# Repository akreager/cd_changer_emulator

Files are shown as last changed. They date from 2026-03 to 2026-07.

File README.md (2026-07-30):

# CD Changer Emulator

**Raspberry Pi-based CD changer emulator for vintage Kenwood car stereos**

Reverse-engineering the proprietary serial protocol used by 1990s Kenwood head units to communicate with their CD changers, and building an open-source emulator that replaces the changer with a Raspberry Pi — enabling unlimited music playback through the original stereo using its factory controls.
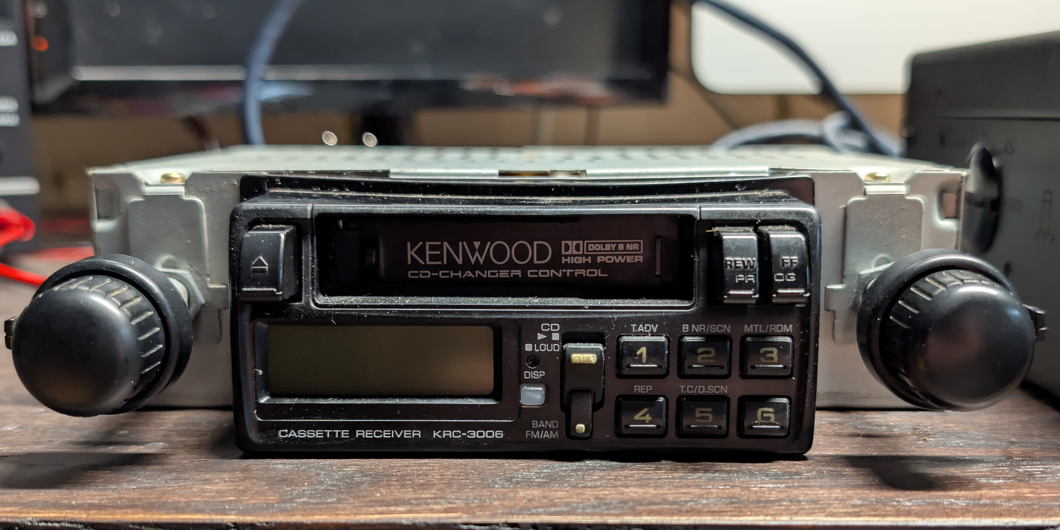
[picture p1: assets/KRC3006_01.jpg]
Close-up front view of KRC-3006 cassette receiver


## Project Status

🔬 **Phase: Protocol Reverse Engineering** — Capturing and decoding the synchronous serial protocol between a Kenwood KRC-3006 cassette receiver and a KDC-C717 10-disc CD changer.

### Current Milestone

**Phase 1 of TP-KRC3006-01 — power-on characterization — is complete.** Executed 2026-04-19 on the KRC-3006 with a KDC-C717 changer connected through the pass-through breakout board. Every recorded step passed; results are published in [TL-KRC3006-01-P1-20260419](./docs/records/TL-KRC3006-01-P1-20260419.pdf).

Findings that matter for the emulator design:

- **CH-CON (Pin 4) measures active-HIGH** — the line rises when the changer source is selected. This *conflicts* with the KDC-CX85 service manual, which documents it as active-LOW. To be re-confirmed against decoded traffic in Phase 2.
- **Pin 2 (GND) and Pin 6 (D.GND) show continuity** inside the head unit, which settles the grounding strategy for the HAT.
- **CLK (Pin 13) is gated, not continuous** — 0 Hz at idle, 31.6 Hz during playback, briefly ~100 Hz on a track change before settling back. These are DMM frequency readings on a gated line, not bit-rate measurements; bit-level clock timing awaits logic analyzer capture in Phase 2A.
- **Pin 10 (CH-DATAC) idles near 5 V**, not the LOW state predicted by the schematic analysis. Unexplained — still open.
- **The KDC-C717 is functional** — displays E-01 with no magazine, then loads and plays on insertion.

Testing runs inline through the DN-KRC3006-04 pass-through breakout board, serial number 1, assembled and verified per TP-KRC3006-02:
Close-up view of assembled pass-through breakout board

The KDC-CX85 originally used as the reference changer was diagnosed with a dead or degraded laser diode and retired. All further testing uses the KDC-C717:
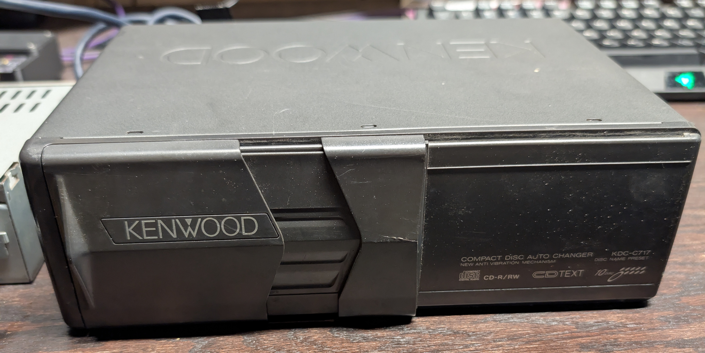
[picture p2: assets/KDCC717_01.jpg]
Close-up front view of KDC-C717 CD auto changer


For reference, the 13-pin mini DIN changer connector pinout:
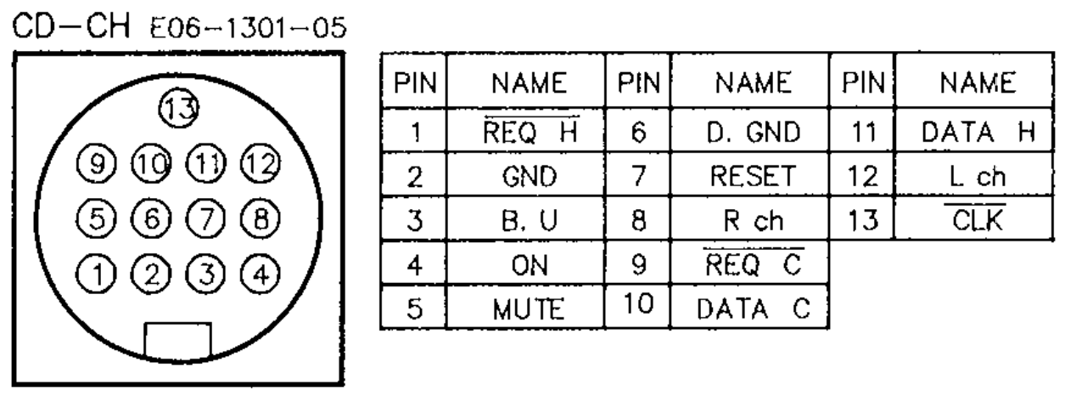
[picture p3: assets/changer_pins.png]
Kenwood 13-pin mini DIN CD changer connector pinout and signal names


### Immediate To-Do

- [ ] **Execute Phase 2A of TP-KRC3006-01** — Idle-state logic analyzer capture and first message decode: establish the bit clock, polling interval, and frame structure.
- [ ] **Execute Phase 2B** — Inline bidirectional capture of head unit ↔ KDC-C717 traffic. Inline capture is mandatory: the head unit will not switch to the changer source unless a changer is electrically present, so isolated head unit testing is impractical.
- [ ] **Execute Phase 3** — Command mapping: correlate each head unit control to its bus command and the changer's response, and compare against the Mictronics tables.
- [ ] **Resolve CLK directionality** — The CX85 service manual lists CLK as I/O. If Phase 2B confirms it is bidirectional, the fixed-direction SN74LVC8T245 will not work for CLK; an SN74LVC1T45 (independent DIR pin) is the planned substitute.
- [ ] **Continue the emulator HAT schematic** — The protocol and audio front end is placed (ATtiny1616, two SN74LVC8T245 level shifters, PCM5102A DAC, 40-pin Pi header, 13-pin mini DIN changer port, supporting passives). The automotive power supply section is not yet drawn and no PCB layout has begun; the schematic cannot be finalized until command mapping is complete.

### Completed

- [x] **Schematic analysis** — Detailed analysis of both KRC-3006 and KDC-CX85 service manuals. Confirmed 5V TTL bus signaling, inline series resistors of 100Ω–7.5KΩ on the head unit side against a uniform 100Ω on the changer side, all total series impedances between 200Ω and 7.6KΩ, COMMSW protocol selection, and always-live 12V on the B.U. pin. **Rev C corrected an earlier error:** R145/R146 (100K) are pull-downs to ground that define the idle-LOW state on DATA H and CLK — they are *not* inline series elements, and bus edges are consequently fast (τ ≈ 2 ns), not slow. No edge-rate compensation is needed. (DN-KRC3006-02 Rev C)
- [x] **Breakout board design** — KiCad layout with two 13-pin mini DIN connectors and 2.54mm pin headers (ground adjacent to each signal) using Kenwood signal names on silkscreen. (DN-KRC3006-04)
- [x] **Connector footprint verification** — 3D-printed mockup confirmed pin spacing before committing to fab.
- [x] **Breakout board ordered** — 3 boards, OSH Park standard fab.
- [X] **Completed TP-KRC3006-02** — Receive, inspect, assemble and verify pass-through breakout board serial number 1.
- [X] **Set up test bench** — Bench wiring, logic analyzer connections, and a custom staged power adapter with two toggle switches that simulate constant and ignition-switched power independently.
- [X] **Troubleshoot CX85** — Initial tests showed the CD changer laser diode is dirty or degraded (E-04, all discs unreadable). Unit deemed inoperable and retired. Further testing is carried out with a KDC-C717 CD changer. (DN-KRC3006-06)
- [X] **Completed Phase 1 of TP-KRC3006-01** — Power-on characterization with the KDC-C717 inline: supply and idle current draw, 13-pin DIN idle voltages on every signal pin, CH-CON polarity, CLK gating behavior, and pin 2 ↔ pin 6 ground continuity. Record: TL-KRC3006-01-P1-20260419.

## What This Project Does

This project emulates a Kenwood CD changer on the 13-pin round DIN connector used by mid-1990s Kenwood head units. The emulator responds to all head unit commands (play, stop, next/previous track, disc selection, repeat, shuffle) and streams audio from a Raspberry Pi through the stereo's built-in amplifier.

### Features (Planned)

- **Full protocol emulation** — Head unit displays disc number and track number.
- **10 virtual disc slots** — Map playlists to CD1–CD0, just like a real magazine. "Magazine overflow" (a playlist of playlists) allows more than ten playlists per magazine, wrapping to the next bank automatically when disc 10 finishes.
- **Web-based library management** — Build playlists and load virtual magazines from your phone over WiFi. FLAC-only library. By design there are **no playback controls in the web UI** — every transport command comes from the head unit, the same as a real changer. (DN-KRC3006-05)
- **Automotive power management** — Supercapacitor-backed graceful shutdown, cranking ride-through, battery monitoring.
- **WiFi standby mode** — When parked at home, the Pi stays on and connects to your home network for easy music transfers and system updates.
- **Custom Raspberry Pi HAT** — Single PCB with ATtiny1616 protocol controller, PCM5102A I2S DAC, automotive power supply, designed for JLCPCB or similar assembly.

## Target Hardware

| Component | Role |
|---|---|
| Kenwood KRC-3006 (or similar mid-90s Kenwood head unit) | The stereo — device under test |
| Kenwood KDC-C717 | CD auto changer — reference changer for protocol capture |
| Raspberry Pi 5 | Media server, web interface, audio playback |
| ATtiny1616 | Real-time Kenwood protocol handler (on custom HAT), run at 3.3V to match Pi GPIO natively |
| SN74LVC8T245PWR ×2 | 3.3V ↔ 5V bus level shifting, one per direction |
| PCM5102A I2S DAC | Digital-to-analog audio conversion |
| 1 TB NVMe SSD | Music storage (avoids SD card corruption) |
| SparkFun TOL-18627 USB Logic Analyzer | Protocol capture and analysis |
| Custom staged power adapter | Two toggle switches simulating constant and ignition power independently on the bench |

## Target Vehicle

Any vintage automobile still using a Kenwood head unit with CD changer control. I am building this and testing around a KRC-3006 head unit due to it being the only shaft style cassette deck with a CD changer control port. My vehicle for this project is a 1985 Chevrolet C10 Silverado. The power supply design accounts for the electrically noisy environment of older vehicles without modern filtering.

## Repository Structure

```
cd_changer_emulator/
├── assets/                  # Project assets. Photos and screenshots.
├── docs/                    # Project documentation
│   ├── TP-KRC3006-01.odt    # Test plan 1: Protocol capture test procedure (IEEE 829)
│   ├── TL-KRC3006-01.ods    # Test log 1: Companion log workbook to TP-KRC3006-01
│   ├── TP-KRC3006-02.odt    # Test plan 2: Breakout board test plan
│   ├── TL-KRC3006-02.odt    # Test log 2: Breakout board test log
│   ├── TP-KRC3006-03.odt    # Test plan 3: Emulator test procedure (IEEE 829)
│   ├── TL-KRC3006-03.ods    # Test log 3: Companion log workbook to TP-KRC3006-03
│   ├── DN-KRC3006-01.md     # Design note 1: HAT design research
│   ├── DN-KRC3006-02.md     # Design note 2: Schematic analysis
│   ├── DN-KRC3006-03.md     # Design note 3: Bluetooth stretch goal
│   ├── DN-KRC3006-04.md     # Design note 4: Breakout board design
│   ├── DN-KRC3006-05.md     # Design note 5: Web application design for library management
│   ├── DN-KRC3006-06.md     # Design note 6: Kenwood CD changer error codes
│   ├── protocol/            # Decoded protocol data
│   └── records/             # Completed, filled-out test logs (published as PDF)
├── firmware/                # ATtiny1616 firmware (Arduino/megaTinyCore)
│   └── src/
├── software/                # Raspberry Pi software
│   ├── flask-app/           # Web interface — legacy name; being superseded by FastAPI
│   ├── mpd-config/          # Legacy name; playback is moving to python-mpv
│   ├── power-mgmt/          # ATtiny UART bridge and power state management
│   └── wifi-manager/        # AP/client mode switching
├── hardware/                # KiCad PCB design files
│   ├── kicad/
│   │   ├── changer cable breakout/  # Pass-through breakout board (complete, fabbed)
│   │   ├── emulator hat/            # Raspberry Pi HAT (schematic in progress)
│   │   └── lib/                     # Shared custom symbols and footprints
│   ├── gerbers/             # Manufacturing files
│   └── bom/                 # Bill of materials with JLCPCB part numbers
├── captures/                # Logic analyzer captures (.sr files)
├── diagrams/                # WaveDrom timing, Mermaid state machines, draw.io blocks
└── reference/               # Datasheets, protocol documentation, forum archives
```

## Kenwood Compatibility

This project targets the **"O protocol"** (Old protocol) used by Kenwood head units with the round 13-pin DIN CD changer connector, roughly 1990–1998. Known compatible head units include models in the KRC series (cassette receivers) and some KDC series (CD receivers) from that era [citation needed].

Later Kenwood units with a rectangular changer connector use the "C protocol" (New protocol), which has different command encoding. This project does not currently target the C protocol, but the hardware and architecture could be adapted [citation needed].

## Documentation

The project follows a documentation-first approach using IEEE 829-inspired test procedures. All documentation lives in the `docs/` directory. Markdown is preferred wherever it fits, so design notes are written in Markdown and render directly on GitHub. The test plans and companion logs are currently kept in Open Document Format because they are table- and form-heavy, but no particular document format is required.

Test plans and test logs are created and maintained as matched pairs sharing a sequence number — `TP-KRC3006-01` defines what gets tested and how, and `TL-KRC3006-01` is where results are recorded. Filled-out copies of a log are published as PDF in `docs/records/` as each phase completes.

| Document Name | Type | Description |
|----|---|---|
| [TP-KRC3006-01](./docs/TP-KRC3006-01.odt) | Test Plan | Initial test plan for capturing messages between CD changer and head unit |
| [TL-KRC3006-01](./docs/TL-KRC3006-01.ods) | Test Log | Companion log workbook to TP-KRC3006-01 |
| [TP-KRC3006-02](./docs/TP-KRC3006-02.odt) | Test Plan | Breakout board test plan |
| [TL-KRC3006-02](./docs/TL-KRC3006-02.odt) | Test Log | Breakout board test log |
| [TP-KRC3006-03](./docs/TP-KRC3006-03.odt) | Test Plan | Test plan for creating and testing protocol emulation through full audio integration |
| [TL-KRC3006-03](./docs/TL-KRC3006-03.ods) | Test Log | Companion log workbook to TP-KRC3006-03 |
| [DN-KRC3006-01](./docs/DN-KRC3006-01.md) | Design Note | HAT design research — ATtiny1616 selection, PCM5102A DAC circuit, automotive power supply with supercap, WiFi architecture, JLCPCB assembly |
| [DN-KRC3006-02](./docs/DN-KRC3006-02.md) | Design Note | Schematic analysis — KRC-3006 head unit and KDC-CX85 changer signal routing, series resistor values, protocol variant identification |
| [DN-KRC3006-03](./docs/DN-KRC3006-03.md) | Design Note | Bluetooth stretch goal — wireless audio streaming while retaining factory head unit controls |
| [DN-KRC3006-04](./docs/DN-KRC3006-04.md) | Design Note | Breakout board design — pass-through 13-pin mini DIN breakout with logic analyzer headers |
| [DN-KRC3006-05](./docs/DN-KRC3006-05.md) | Design Note | Web Application Design for Emulator Library Management |
| [DN-KRC3006-06](./docs/DN-KRC3006-06.md) | Design Note | Kenwood CD Changer Error Codes |

Per-document revision status is tracked in the [documentation index](./docs/README.md).

### Completed Test Records

| Record | Covers | Date |
|----|---|---|
| [TL-KRC3006-01-P1-20260419](./docs/records/TL-KRC3006-01-P1-20260419.pdf) | TP-KRC3006-01 Phase 1 — power-on characterization | 2026-04-19 |
| [TL-KRC3006-02-01-20260410](./docs/records/TL-KRC3006-02-01-20260410.pdf) | TP-KRC3006-02 — breakout board serial number 1 | 2026-04-10 |

## Building / Contributing

This project is in early development. If you have a compatible Kenwood head unit and want to help with protocol capture, testing, or firmware development, contributions are welcome.

### Prerequisites

- [Arduino IDE](https://www.arduino.cc/en/software) with [megaTinyCore](https://github.com/SpenceKonde/megaTinyCore) installed
- [PulseView](https://sigrok.org/wiki/PulseView) for logic analyzer captures
- [KiCad](https://www.kicad.org/) for PCB design
- Python 3 with [FastAPI](https://fastapi.tiangolo.com/) for the web interface and [python-mpv](https://github.com/jaseg/python-mpv) for playback
- [LibreOffice](https://www.libreoffice.org/) to open the test plans and logs (`.odt` / `.ods`)
- A UPDI programmer for the ATtiny1616 ([Adafruit UPDI Friend](https://www.adafruit.com/product/5879) or DIY with a serial adapter and resistor)

## References

- [Mictronics CDC Protocol Documentation](https://www.mictronics.de/) (Kenwood command tables)
- [Elektroda.pl Kenwood Slim CD Changer Emulator](https://www.elektroda.pl/rtvforum/topic536235.html) (szymtro's 8051 implementation)
- [AVRFreaks: Kenwood CD Changer → Serial Strings](https://www.avrfreaks.net/forum/kenwood-cd-changer-serial-strings)
- [Pinouts.ru: Kenwood 13-pin DIN connector](https://old.pinouts.ru/CarAudio/kenwood_cd_changer_pinout.shtml)
- [SpenceKonde/megaTinyCore](https://github.com/SpenceKonde/megaTinyCore) (ATtiny1616 Arduino support)
- [pyupdi / pymcuprog](https://github.com/mraardvark/pyupdi) (UPDI programming from Raspberry Pi)

## License

This project is licensed under the [MIT License](LICENSE) — you're free to use, modify, and distribute this project for any purpose, including commercial use.

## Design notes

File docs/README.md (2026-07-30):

# KRC-3006 CD Changer Emulator — Documentation Index

This folder contains all project documentation for the KRC-3006 reverse engineering and CD changer emulator project.

---

## File Format

There is no mandated document format. **Markdown (`.md`) is preferred wherever it fits** — such as the design notes and this README — so documents render directly on GitHub. Table- and form-heavy documents like the test plans and logs are currently kept in Open Document Format (`.odt` / `.ods`) and open in LibreOffice or any compatible editor, but any format may be used where it serves the document best.

Formats currently in use:
- Markdown (`.md`) — design notes and READMEs
- Open Document Format (`.odt` / `.ods`) — test plans and logs
- Timing diagrams (WaveDrom `.json`)
- State machine diagrams (Mermaid `.mmd`)

---

## Naming Convention

Documents follow this structure:

```
TT-KRC3006-NN
```

| Field | Description |
|---|---|
| `TT` | Two-letter document type code (see below) |
| `KRC3006` | Project identifier — fixed for all documents in this project |
| `NN` | Two-digit sequence number, zero-padded (01, 02, 03 …) |

### Document Type Codes

| Code | Type | Description |
|---|---|---|
| `TP` | Test Plan | Defines test objectives, scope, phases, pass/fail criteria, and procedure for a body of testing work. |
| `TL` | Test Log | Companion data-collection workbook to a Test Plan. Captures actual results, observations, and outcomes as testing is executed. Always paired 1:1 with a TP of the same number. |
| `DN` | Design Note | Records design decisions, research findings, architectural intent, or reference material. Not a procedure document — captures the *why* and *what*, not the *how*. |

---

## Document Register

| Document | Title | Paired With | Status |
|---|---|---|---|
| TP-KRC3006-01 | Protocol Reverse Engineering Test Plan | TL-KRC3006-01 | **Rev B** — in progress; Phase 1 complete |
| TL-KRC3006-01 | Test Log — Companion to TP-01 | TP-KRC3006-01 | **Rev B** — Phase 1 recorded 2026-04-19 |
| TP-KRC3006-02 | Breakout Board Bare Board Testing, Assembly, and Verification | TL-KRC3006-02 | Board Serial Number 1 Completed |
| TL-KRC3006-02 | Breakout Board Test Log | TP-KRC3006-02 | Board Serial Number 1 Completed |
| TP-KRC3006-03 | Protocol Emulation Test Plan | TL-KRC3006-03 | Waiting for TP-01 Completion |
| TL-KRC3006-03 | Test Log — Companion to TP-03 | TP-KRC3006-03 | Template prepared; waiting for TP-01 Completion |
| DN-KRC3006-01 | Hardware Design Research | — | In progress |
| DN-KRC3006-02 | Schematic Analysis | — | **Rev C** — bus impedance corrected |
| DN-KRC3006-03 | Bluetooth Integration & Button Remapping | — | Concept |
| DN-KRC3006-04 | 13-Pin Mini DIN Protocol Sniffer Breakout Board | — | Complete |
| DN-KRC3006-05 | Web Application Design for Emulator Library Management | — | Draft |
| DN-KRC3006-06 | Kenwood CD Changer Error Codes | — | Complete |

TP-KRC3006-01 Rev B (2026-04-12) restricted the plan's scope to protocol reverse engineering only — emulator development and audio integration moved to TP-KRC3006-03 — replaced KDC-CX85 references with the KDC-C717, and added Phase 2B for changer-connected capture through the breakout board.

### TP-KRC3006-01 Phase Progress

| Phase | Scope | Status |
|---|---|---|
| 1 | Power-on characterization — supply, idle bus voltages, CH-CON polarity, ground continuity | Complete (2026-04-19) |
| 2A | Idle-state capture and first message decode | Not started |
| 2B | Inline bidirectional capture, head unit ↔ KDC-C717 | Not started |
| 3 | Command mapping | Not started |

---

## TP / TL Pairing

Test Plans and Test Logs are always created and maintained as a matched pair. A TP defines what will be tested and how; the companion TL is where results are recorded as work is executed. They share the same sequence number — `TP-KRC3006-01` and `TL-KRC3006-01` are two halves of the same body of test work.

When a new test plan is created, a corresponding log document must be created at the same time. A filled out *copy* of a test log is to be placed in the `records/` sub directory.

The working log in this folder stays live and accumulates results as phases are executed. Each time a phase or unit is finished, a snapshot of the filled-out log is published to `records/` and named `{TL-ID}-{phase or unit}-{YYYYMMDD}`.

### Published Records

| Record | Covers | Date |
|---|---|---|
| TL-KRC3006-01-P1-20260419 | TP-01 Phase 1 — power-on characterization | 2026-04-19 |
| TL-KRC3006-02-01-20260410 | TP-02 — breakout board serial number 1 | 2026-04-10 |

---

*This README is a living document and should be updated whenever a new document is added to the register.*

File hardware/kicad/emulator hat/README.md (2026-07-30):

# Kenwood CD Changer Emulator HAT

KiCad project for a Raspberry Pi 5 HAT that emulates a Kenwood CD changer over the proprietary "O protocol" bus. Designed for the KRC-3006 shaft-style cassette head unit, replacing a 10-disc changer with unlimited FLAC playback controlled entirely from the factory head unit.

## Current Status

**Early schematic layout.** The protocol and audio front end is placed — ATtiny1616, two SN74LVC8T245 level shifters, PCM5102A DAC, 40-pin Pi header, and the 13-pin mini DIN changer port — along with supporting passives based on the PCM5102A reference design. The automotive power supply section has not been drawn yet, and no PCB layout work has begun.

Protocol reverse engineering via the breakout board (DN-KRC3006-04) is the active priority. Full command mapping must be complete before the HAT schematic can be finalized.

## Design Overview

The HAT consolidates four subsystems onto a single board:

- **ATtiny1616 protocol controller** — Handles all real-time Kenwood bus communication at 3.3V, translated to 5V bus levels via two SN74LVC8T245PWR level shifters. Communicates with the Pi over a dedicated UART.
- **PCM5102A I2S DAC** — Converts digital audio from the Pi to analog line-level output for the head unit's CD changer input.
- **Automotive power supply** — Accepts 12V from the head unit (constant B.U. and ignition-switched), regulates to 5V/3.3V with power sequencing and soft-shutdown support.
- **Connectors and interface** — 13-pin mini DIN bus connection, UPDI programming header (dedicated UART3 on GPIO4/5), status LEDs, test points.

Every bus signal will carry a 100 Ω inline series resistor, matching the protection scheme the KDC-CX85 uses on its own connector. Per DN-KRC3006-02 Rev C the bus is a conventional fast 5V TTL/CMOS bus — the head unit's own series resistors range from 100 Ω to 7.5 KΩ and the 100K parts on DATA H and CLK are pull-downs to ground that define the idle-LOW state, not series elements. No edge-rate compensation or Schmitt-trigger conditioning is needed.

All music logic — playlist management, FLAC decoding, library browsing — runs on the Raspberry Pi via python-mpv. The ATtiny handles only the protocol state machine and handshake timing.

## Settled by Phase 1 Testing

TP-KRC3006-01 Phase 1 (power-on characterization, 2026-04-19) resolved two questions that affect this board:

- **Audio ground topology** — Pins 2 (GND) and 6 (D.GND) measured continuous inside the head unit. They can be treated as a single ground on the HAT.
- **CH-CON (Pin 4) polarity** — Measured active-HIGH: the line rises when the changer source is selected. This conflicts with the KDC-CX85 service manual, which documents it as active-LOW, so it will be re-confirmed against decoded traffic in Phase 2 before the input stage is committed.

Phase 1 also found Pin 10 (CH-DATAC) idling near 5 V rather than the LOW state the schematic analysis predicted. That is still unexplained and may affect how the HAT drives or reads that line.

## Open Constraints

Several items still depend on data from the ongoing reverse engineering effort (TP-KRC3006-01):

- **CLK signal directionality** — The CX85 service manual lists CLK as I/O on the changer side. If Phase 2B confirms it is bidirectional, the CLK channel must use an SN74LVC1T45 (independent DIR pin) instead of the fixed-direction 74LVC8T245.
- **Power sequencing** — The ATtiny must be ready to respond before the Pi finishes booting (~20s). Autonomous status responses during early boot may be required.
- **DAC output level matching** — Analog output must match the stock changer's level to avoid volume discontinuity. To be verified during integration testing.

## Related Documentation

| Document | Description |
|---|---|
| DN-KRC3006-01 | HAT design research — component selection, pin mapping, architecture |
| DN-KRC3006-02 Rev C | KRC-3006 and KDC-CX85 schematic analysis — bus impedance, signal conditioning |
| DN-KRC3006-04 | 13-pin mini DIN breakout board (complete, used for protocol capture) |
| TP-KRC3006-01 Rev B | Reverse engineering test plan (active — Phase 1 complete, Phase 2A next) |
| TP-KRC3006-03 | Emulator development and integration test plan (waiting for TP-01) |

## License

MIT — see repository root.

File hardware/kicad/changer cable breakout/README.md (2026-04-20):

# KRC-3006 Pass-Through Breakout Board (DN-KRC3006-04)

## Purpose

This KiCad project implements a passive, pass-through breakout board for the Kenwood KRC-3006 head unit's 13-pin mini DIN connector. The board provides:

- **Signal routing** between the KRC-3006 and connected CD autochanger.
- **Accessible test points** for bus signal analysis and protocol reverse engineering.
- **Isolated audio path** with independent head unit and changer TRS audio jack connectors.

## Current Status

**COMPLETE AND TESTED** — Boards received 2026-03-28 from OSH Park. Assembly and verification of S/N 1 completed 4/5. Breakout board is fully functional and ready for protocol reverse engineering work.  
Picture of assembled break-out board

## Schematic Summary

| Ref Des | Component | Function |
|---|---|---|
| J1 | SDD-130J, 13-pin mini DIN female | Head unit side connector (front side) |
| J2 | SDD-130J, 13-pin mini DIN female | Changer side connector (back side) |
| J3 | 1×11 female pin header, 2.54 mm pitch | Digital/control signal test points |
| J4 | STX-3100-3NB, 3.5 mm TRS audio jack | Head unit side audio breakout |
| J5 | STX-3100-3NB, 3.5 mm TRS audio jack | Changer side audio breakout |

## J1/J2 Pinout
13Pin Mini Din Pinout
| Pin | Signal | Description |
|-----|---|---|
| 1 | REQ H (Active Low)  | Request handshake output from head unit. |
| 2 | GND | Audio ground. |
| 3 | B.U.  | Battery Unswitched. |
| 4 | ON  | Changer connect/enable signal. |
| 5 | MUTE  | Mute request line. |
| 6 | D. GND | Digital ground. |
| 7 | RESET  | Reset pulse output to changer. |
| 8 | R CH  | Right audio channel, analog. |
| 9 | REQ C (Active Low)  | Request handshake output from changer to head unit. |
| 10 | DATA C  | Serial data from changer to head unit. |
| 11 | DATA H  | Serial data from head unit to changer. |
| 12 | L CH  | Left audio channel, analog. |
| 13 | CLK (Active Low)  | Synchronous clock. |

## J3 Pinout

|  J3 Pin  |  J1 Pin  |  Signal  |
| --- | --- | --- |
| 1 | 2 |  GND  |
| 2 | 4 |  ON (CH-CON)  |
| 3 | 3 |  B.U. (+14V)  |
| 4 | 7 |  RESET  |
| 5 | 6 |  D. GND  |
| 6 | 1 |  REQ H (Active Low)  |
| 7 | 9 |  REQ C (Active Low)  |
| 8 | 5 |  MUTE  |
| 9 | 10 |  DATA C  |
| 10 | 11 |  DATA H  |
| 11 | 13 |  CLK (Active Low)  |

## J4 Pinout

| J4 Pin | J1 Pin | Signal |
| --- | --- | --- |
| 1 | 2 | GND |
| 2 | 8 | L CH to head unit |
| 3 | 12 | R CH to Head unit |

## J5 Pinout

| J5 Pin | J2 Pin | Signal |
| --- | --- | --- |
| 1 | 2 | GND |
| 2 | 8 | L CH from changer |
| 3 | 12 | R CH from changer |

## Audio Interception

The audio channels (Pin 8 - R CH and Pin 12  L CH) are not routed as a direct pass-through between J1 and J2. Instead, they are broken out to two 3.5 mm TRS audio jacks mounted on the right edge of the board:

- **J4** — Head unit side audio. Tip = R CH, Ring = L CH, Sleeve = GND.
- **J5** — Changer side audio. Tip = R CH, Ring = L CH, Sleeve = GND.

The audio jacks use a standard 3-conductor (TRS) footprint with no switching contacts. When nothing is plugged in, the audio pins on both the head unit and changer sides float.

This topology enables three operating modes:

| Mode | Configuration | Use Case |
|---|---|---|
| **Audio pass-through** | Connect J4 to J5 with a male-to-male 3.5 mm TRS cable. | Normal protocol capture with authentic changer audio reaching the head unit. |
| **Audio intercept** | Connect monitoring equipment (oscilloscope, audio recorder, powered speakers) to J5. | Listen to or record the changer's audio output without routing it to the head unit. |
| **Audio injection** | Connect an external audio source to J4. Leave J5 disconnected or connected to monitoring equipment. | Feed test tones or music from a phone, DAC, or Raspberry Pi directly into the head unit's audio input path. Useful for verifying the audio path independently of changer protocol state. |

Audio pass-through requires the external cable. The board cannot function as a fully transparent sniffer without it. This is an intentional design decision — the separate jacks provide flexibility that a hardwired pass-through cannot.

## Next Steps

This board is now ready to support:
1. **TP-KRC3006-01 Phase 1** — Passive capture of KRC-3006 ↔ KDC-C717 traffic
2. **TP-KRC3006-01 Phase 2a/2b** — Analysis with head unit alone, then with real changer through breakout
3. **TP-KRC3006-03** — Emulator development and integration testing

## References

- Service manual: Kenwood KRC-3006 Cassette Head Unit
- Service manual: Kenwood KDC-C717 CD Changer
- Related design docs: DN-KRC3006-02 (Schematic Analysis), DN-KRC3006-04

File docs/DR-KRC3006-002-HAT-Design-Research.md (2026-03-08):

# KRC-3006 CD Changer Emulator — Raspberry Pi HAT Design Research

## Document ID: DR-KRC3006-002
**Date:** ___  
**Author:** ___  
**Status:** Pre-design research — to inform schematic and layout

---

## 1. System Architecture Overview

The final product is a single Raspberry Pi HAT PCB that plugs onto the Pi 3B+ GPIO header and provides everything needed to emulate a Kenwood CD changer. The HAT consolidates four subsystems:

1. **ATtiny1616 Protocol Controller** — Handles all real-time Kenwood bus communication
2. **PCM5102A I2S DAC** — Converts digital audio from the Pi to analog line-level output
3. **Automotive Power Supply** — Steps 12V from the Kenwood head unit down to 5V and 3.3V
4. **Connectors & Interface** — 13-pin DIN breakout, UPDI programming header, status LEDs

The Raspberry Pi 3B+ provides: WiFi AP for the web control interface, media storage (USB or SD), audio playback via MPD/Flask, and UART communication with the ATtiny.

---

## 2. ATtiny1616 Selection Rationale

### Why ATtiny1616 (not ATtiny85 or ATtiny3216)

| Parameter | ATtiny85 | ATtiny1616 | ATtiny3216 |
|---|---|---|---|
| Pins (GPIO) | 6 | 18 | 18 |
| Flash | 8KB | 16KB | 32KB |
| SRAM | 512B | 2KB | 2KB |
| Hardware UART | No (USI only) | Yes (1x) | Yes (1x) |
| Hardware SPI | No (USI only) | Yes (1x) | Yes (1x) |
| Ext. Interrupts | Limited | All pins | All pins |
| CCL (Custom Logic) | No | Yes (2 LUT) | Yes (2 LUT) |
| Max Clock | 20MHz | 20MHz | 20MHz |
| JLCPCB Part # | Various | **C507118** | C507136 |
| JLCPCB Price | ~$0.30 | **~$0.49** | ~$0.80 |
| Package | SOIC-8 | **QFN-20 (3x3mm)** | QFN-20 (3x3mm) |

**Decision: ATtiny1616** — The ATtiny85 simply doesn't have enough I/O (need 7 bus pins + UART TX/RX = 9 minimum). The 1616 provides exactly what's needed with headroom. The 3216 doubles the flash but is otherwise identical and costs more — 16KB is plenty for the protocol state machine.

### JLCPCB Assembly Notes
- JLCPCB Part: **C507118** (ATTINY1616-MNR, QFN-20-EP 3x3mm)
- Assembly type: SMT, compatible with both Economic and Standard PCBA
- MSL Level 1 (no baking required)
- The QFN-20 package requires proper thermal pad design — include thermal vias under the exposed pad

### Pin Assignment Plan

The ATtiny1616 in the QFN-20 package has pins PA0-PA7 and PB0-PB5, plus the UPDI pin (PA0 is shared with UPDI by default but can be freed via fuse setting).

**Recommended pin mapping:**

| ATtiny Pin | Function | Kenwood Signal | Direction | Notes |
|---|---|---|---|---|
| PA1 | UART TX | → Pi GPIO15 (RXD) | Output | Hardware USART0 TXD |
| PA2 | UART RX | ← Pi GPIO14 (TXD) | Input | Hardware USART0 RXD |
| PA3 | SPI SCK | CLK (Pin 13) | Input | Use as ext interrupt for clock |
| PA4 | SPI MOSI | CH-DATAH (Pin 11) | Input | Data from head unit |
| PA5 | SPI MISO | CH-DATAC (Pin 10) | Output | Data to head unit |
| PA6 | GPIO | CH-REQH (Pin 1) | Input | Ext interrupt on falling edge |
| PA7 | GPIO | CH-REQC (Pin 9) | Output | Changer handshake |
| PB0 | GPIO | CH-CON (Pin 4) | Input | Changer connect detect |
| PB1 | GPIO | CH-MUTE (Pin 5) | Output | Mute request |
| PB2 | GPIO | CH-RST (Pin 7) | Input | Reset detect |
| PB3 | GPIO | Status LED 1 | Output | Activity indicator |
| PB4 | GPIO | Status LED 2 | Output | Error indicator |
| PB5 | GPIO | (spare) | — | Reserve for future use |
| PA0 | UPDI | Programming | Bidir | In-circuit programming from Pi |

### Level Shifting: NOT Required
Both the ATtiny1616 (running at 5V) and the Kenwood bus (5V TTL) are at the same voltage level. However, the Pi's GPIO is 3.3V. For the UART connection:
- **ATtiny TX → Pi RX**: Needs a voltage divider (2.2kΩ / 3.3kΩ) to drop 5V to ~3.3V
- **Pi TX → ATtiny RX**: The ATtiny's 5V logic reads 3.3V as HIGH (Vih min = 0.6×Vcc = 3.0V at 5V supply, so 3.3V is marginal). Run the ATtiny at 3.3V instead if this is a concern, OR add a level shifter IC. Running at 3.3V simplifies things significantly but must be verified against Kenwood bus voltage requirements.

**Alternative: Run ATtiny1616 at 3.3V** — The 1616 operates from 1.8V to 5.5V and runs at full 20MHz speed at 3.3V. The Kenwood bus is 5V but the ATtiny's 3.3V output high would read as 3.3V on the bus. Whether the Kenwood head unit reads 3.3V as a valid HIGH needs verification during Phase 3 testing. If it doesn't work, add a 74LVC245 or TXB0108 level shifter.

### UPDI In-Circuit Programming from the Pi
The ATtiny 1-series uses UPDI (Unified Program and Debug Interface) — a single-wire protocol that can be driven by a standard UART with a resistor and diode. The pyupdi/pymcuprog tools run on the Pi.

**Circuit for Pi-based UPDI programming:**
```
Pi GPIO14 (TX) ---[470Ω]---+--- ATtiny UPDI pin
                            |
Pi GPIO15 (RX) ---[Schottky]---+
                  (cathode to TX side)
```
A GPIO-controlled MOSFET can disconnect this circuit during normal operation so the UART is free for the ATtiny ↔ Pi command link. Alternatively, use a second UART (the Pi 3B+ has a mini-UART on GPIO14/15 and the PL011 UART available when Bluetooth is moved).

---

## 3. PCM5102A I2S DAC Circuit

### I2S Connection to Pi GPIO Header

| Pi GPIO | Pi Header Pin | PCM5102A Pin | Signal |
|---|---|---|---|
| GPIO18 | Pin 12 | BCK | Bit clock |
| GPIO19 | Pin 35 | LRCK | L/R word clock |
| GPIO21 | Pin 40 | DIN | Serial data |
| — | — | SCK | **Tie to GND** (self-generated) |

### PCM5102A Configuration Pins (active-LOW, active during power-up)

| Pin | Setting | Effect |
|-----|---|---|
| FMT (H4L) | **LOW** (GND) | I2S format (required for Pi) |
| FLT (H1L) | LOW (GND) | Normal latency filter |
| DMP (H2L) | LOW (GND) | Normal de-emphasis |
| XSMT | **HIGH** (3.3V via 47kΩ pull-up) | Soft-mute OFF (unmuted) |

### Key Design Points
- **Power**: 3.3V only (from the on-board LDO, NOT from the Pi's 3.3V rail — keep DAC power isolated)
- **Decoupling**: Place 10µF + 100nF ceramic caps close to AVDD, DVDD, and CPVDD pins per TI datasheet Figure 38
- **Charge pump caps**: 2x 2.2µF between CAPP/CAPN pins (generates internal negative rail for bipolar output swing)
- **Output coupling caps**: 2x 2.2µF in series with each audio output (OUTL, OUTR) → to Kenwood pins 12 and 8
- **Output filter**: Optional low-pass RC filter after coupling caps (1kΩ + 100pF = ~1.6MHz cutoff) to suppress any ultrasonic content
- **Ground**: Separate analog ground pour under the DAC, connected to digital ground at a single star point

### Linux Configuration
Add to `/boot/config.txt`:
```
dtoverlay=hifiberry-dac
```
Verify with: `aplay -l` → should show `snd_rpi_hifiberry_dac`

### JLCPCB Parts
- PCM5102A: Search JLCPCB parts library — TI's PCM5102APWR (TSSOP-20) is the target. **Check stock before layout** — this part has had availability issues. The PCM5102 (non-A) is an acceptable alternative (same pinout, slightly different specs).
- If PCM5102A is unavailable at JLCPCB, consider: (a) using a pre-built GY-PCM5102 module soldered to the HAT via header pins, or (b) switching to PCM5122 which adds I2C volume control but requires a more complex driver setup.

---

## 4. Automotive Power Supply & Energy Storage

### 4.1 Target Vehicle: 1985 Chevrolet C10/K10 Silverado

The target installation vehicle significantly impacts power supply design. An '85 Silverado presents a harsher electrical environment than modern vehicles:

- **Ignition system**: GM HEI (High Energy Ignition) distributor — every spark event collapses an ignition coil inside the distributor cap, generating broadband EMI pulses that couple into the wiring harness. No modern ECU filtering or shielded ignition wires.
- **Charging system**: Internal-regulator alternator with no smart voltage management. Output is a relatively coarse 13.8–14.8V with significant AC ripple. Aging diodes in a 40-year-old alternator (even a replacement) can pass AC into the DC bus.
- **Cranking behavior**: The starter motor draws 150–250A. Battery voltage sags to 8V or lower during cranking, especially on cold Ohio mornings. The sag lasts 1–5 seconds depending on engine temperature and battery condition.
- **Load dump transients**: When large inductive loads disconnect (A/C compressor clutch, blower motor), voltage spikes of 40V+ can occur for microseconds to milliseconds.
- **Wiring age**: 40-year-old wiring with potentially corroded grounds and increased resistance throughout. Voltage drops across connectors may be significant.
- **No modern filtering**: No CAN bus, no body control module, no suppression capacitors on relays. What the alternator and ignition system produce, the wiring carries.

**Does the Kenwood head unit protect us?**
The KRC-3006 has its own internal voltage regulation for its logic and display, so the head unit itself survives automotive environments. However, Pin 3 (+12V) on the changer connector is almost certainly just battery voltage routed through a fuse and possibly a small series inductor — it was designed to power a CD changer's motors and laser optics, not sensitive digital electronics. The head unit protects *itself* but does NOT provide a clean, regulated, filtered supply on the changer port. **Verify this by examining the service manual schematic for the Pin 3 supply path.** The HAT must include its own full input protection and filtering.

### 4.2 Requirements

| Rail | Voltage | Max Current | Consumer |
|---|---|---|---|
| 5V | 5.0V ±5% | 2.5A | Raspberry Pi 3B+ (via GPIO header pins 2,4) |
| 3.3V | 3.3V ±3% | 200mA | ATtiny1616, PCM5102A, EEPROM, LEDs |

Input: 12V nominal from Kenwood Pin 3 (actual range in an '85 Silverado: 8V during cranking, 14.5V running, 40V+ transient spikes)

### 4.3 Input Protection Circuit (Strengthened for Vintage Vehicle)

```
Pin 3 (+12V) → [PTC fuse] → [Schottky] → [TVS] → [Pi-filter: C-L-C] → VBATT_FILT
```

**Full chain, in order from connector to buck converter input:**

1. **PTC resettable fuse** (1812 package, 2A hold / 4A trip): First line of defense against dead shorts during prototyping or wiring errors. Self-resetting means you don't blow a one-time fuse during development.

2. **Reverse polarity protection**: SS34 Schottky diode (40V, 3A) in series — low forward drop (~0.5V). Protects against accidentally swapping wires on the DIN connector. On an '85 Silverado with no polarity-protected connectors elsewhere in the vehicle, this is essential.

3. **Transient voltage suppression**: SMAJ24A TVS diode (24V standoff, 400W peak pulse power) from VBATT to GND. Clamps load dump spikes to ~39V (clamping voltage at 1A). This is the primary defense against the 40V+ transients that occur when inductive loads disconnect.

4. **Pi-filter for EMI** (upgraded from single LC for the HEI ignition environment):
   ```
   VBATT_PROT → [100µF electrolytic] → [22µH inductor, ≥3A sat] → [100µF electrolytic + 100nF ceramic] → VBATT_FILT
   ```
   The pi-filter (capacitor-inductor-capacitor) provides significantly better high-frequency rejection than a single LC stage. The first cap absorbs sharp transient edges from HEI ignition pulses. The inductor blocks conducted EMI. The second cap provides a clean, low-impedance supply to the buck converter input. The 100nF ceramic in parallel with the output electrolytic handles high-frequency noise that electrolytics are too slow to absorb.

   **Why a pi-filter matters for this vehicle**: HEI ignition pulses contain energy from DC up through 100+ MHz. A single LC filter has a resonant peak that can actually amplify noise at its resonant frequency. The pi-filter's double capacitive termination damps this resonance and provides a steeper rolloff.

5. **Optional: Common-mode choke** on the 12V and GND lines entering the HAT, before the pi-filter. This suppresses differential AND common-mode noise from the vehicle wiring harness. A Würth 744272102 or similar SMD common-mode choke rated for DC current would go here. This is the "belt and suspenders" approach for audio quality — if you hear alternator whine through the speakers during testing, add this.

### 4.4 12V → 5V Buck Converter

**Recommended: TPS5430DDAR** (TI)
- **5.5V–36V input range** — critical: survives automotive transients that the TVS clamps to ~39V
- 3A output continuous
- 500kHz switching frequency
- Widely available on JLCPCB/LCSC (check current stock)
- Well-documented application circuit in datasheet
- Internal UVLO (under-voltage lockout) at 5.5V — converter shuts down cleanly if input sags below this during cranking, rather than producing garbage output

**Alternative: MP1584EN** (MPS)
- Very popular on JLCPCB, often "basic" part = lower assembly fee
- **4.5V–28V input** — NOTE: lower max input than TPS5430. The TVS clamp voltage (~39V) exceeds this rating. If using MP1584, you MUST ensure the TVS clamps below 28V, or add a series resistor to drop voltage before the converter. **The TPS5430 is preferred for this vehicle.**
- 3A output, smaller package (SOIC-8)

**Layout critical**: Keep the input cap → SW pin → inductor → output cap loop as tight as possible. Place input caps directly adjacent to VIN and GND pins. Unbroken ground pour under the converter with vias to inner/back ground plane. Place the buck converter as far from the PCM5102A DAC as board space allows — opposite corners of the HAT is ideal.

### 4.5 5V → 3.3V LDO

**Recommended: AMS1117-3.3** (LCSC basic part, SOT-223)
- 1A output (far more than needed)
- Low cost, universally available at JLCPCB
- ~1.1V dropout means it works from 4.5V+ input
- Place 10µF tantalum + 100nF ceramic on input and output
- Position this LDO near the DAC, not near the buck converter — it acts as a secondary filter stage for the DAC's 3.3V supply

### 4.6 Supercapacitor Energy Storage

The supercap serves **three critical functions**:

1. **Graceful shutdown**: When ignition is turned off, the supercap provides enough energy for the Pi to execute `shutdown -h now` and complete filesystem sync, preventing SD card corruption.
2. **Cranking ride-through**: During engine cranking, battery voltage sags to 8V or below. The buck converter's UVLO may trip at 5.5V input, causing a momentary 5V dropout. The supercap holds the Pi's 5V rail steady through the 1–5 second cranking event.
3. **Brownout/glitch immunity**: Brief voltage dips from load switching (headlights, blower motor, power windows) are absorbed by the supercap without disturbing the Pi.

#### Energy Budget

**Graceful shutdown scenario:**
- Pi 3B+ during shutdown (headless, no USB devices): ~400–500mA at 5V
- Shutdown duration (lean Raspberry Pi OS Lite, non-essential services disabled): 5–8 seconds
- Energy needed: 0.5A × 5V × 8s = **20 joules**, plus margin

**Cranking ride-through scenario:**
- Pi running normally: ~500mA at 5V
- Cranking duration (worst case, cold start): 5 seconds
- Energy needed: 0.5A × 5V × 5s = **12.5 joules**

The shutdown scenario dominates. Target: **30 joules minimum** (50% safety margin).

#### Supercap vs. LiPo: Why Supercap Wins for This Application

| Factor | Supercap | LiPo |
|---|---|---|
| Temperature range | -40°C to +65°C | 0°C to +45°C (charge) |
| Ohio winter (-20°F) | Works fine | Cannot charge, may be damaged |
| Ohio summer (car interior 60°C+) | Works fine | Degrades rapidly, swelling risk |
| Cycle life | 500,000+ cycles | 300–500 cycles |
| Fire risk in hot car | None | Non-trivial |
| Self-discharge | Higher (days) | Lower (weeks) |
| Charge management | Simple (resistor) | Complex IC required |
| Aging/replacement | 10+ year life | 2–3 year replacement cycle |

**Verdict**: The supercap's temperature tolerance alone is decisive for an automotive application in Ohio. A LiPo would need active thermal management or seasonal removal, which is absurd for a car stereo accessory. The supercap's higher self-discharge is irrelevant because it recharges in seconds whenever the engine is running.

#### Recommended Implementation: Direct 5V Rail Supercap

The simplest effective approach is a supercap directly on the 5V output rail, with the ATtiny managing the shutdown logic.

**Component: 5.5V 10F coin-type supercapacitor** (e.g., Eaton HV1030-2R7106-R or similar)
- Pre-balanced dual-cell module in a single radial package
- ~21mm diameter × 8mm tall — fits on the HAT
- Rated 5.5V max (two 2.7V cells internally balanced)
- Cost: ~$3–5

**Energy calculation with 10F cap on 5V rail:**
- Usable voltage range: 5.0V (charged) → 4.6V (Pi minimum before brownout)
- Usable energy: ½ × 10 × (5.0² − 4.6²) = ½ × 10 × (25 − 21.16) = **19.2 joules**
- At 500mA draw: 10F × 0.4V / 0.5A = **8 seconds** — tight for shutdown

**Upgraded: 5.5V 22F supercapacitor** (slightly larger, ~25mm diameter)
- Usable energy: ½ × 22 × 3.84 = **42.2 joules**
- At 500mA draw: 22 × 0.4 / 0.5 = **17.6 seconds** — comfortable for shutdown
- At 500mA draw during 5-second cranking: voltage drops only ~0.11V — cranking is invisible to the Pi

**Recommendation: Use a 22F / 5.5V supercap.** The extra size and cost (~$1 more) buys substantial margin for both shutdown and cranking scenarios.

#### Supercap Charging & Isolation Circuit

```
Buck converter 5V output
        |
        +---[2.2Ω charge resistor]---+---[Schottky diode, cathode→cap]---+--- SUPERCAP (+)
        |                            |                                    |
        |                            +--- 5V_RAIL (to Pi, ATtiny, DAC)   |
        |                                                                 |
        +--- GND --------------------------------------------------------+--- SUPERCAP (−)
```

**Key components:**

1. **Charge-limiting resistor (2.2Ω, 1W)**: Limits inrush current when the supercap is empty at power-on. Without this, a discharged 22F cap looks like a dead short to the buck converter — it would current-limit or shut down. At 5V across 2.2Ω, initial inrush is limited to ~2.3A, which the buck converter can handle. The cap charges to 90% in about τ = R×C = 2.2 × 22 = 48 seconds. This is fine — the Pi takes 20 seconds to boot anyway.

2. **Schottky diode (SS14 or BAT54)**: Cathode toward the supercap, anode toward the 5V rail. This prevents the supercap from backfeeding into the buck converter when 12V input disappears. When 12V drops, the buck converter output collapses, and the supercap becomes the sole power source — current flows from the cap through the 5V rail to the Pi, with the diode blocking reverse flow into the dead converter.

3. **Diode bypass consideration**: The Schottky diode has a ~0.3V forward drop, meaning the supercap charges to ~4.7V rather than 5.0V. This reduces available energy slightly. To mitigate: use a very low-Vf Schottky (e.g., PMEG2010 at ~0.2V), or accept the reduced margin (still workable with a 22F cap).

**Alternative: Use a P-channel MOSFET as an ideal diode** instead of the Schottky. This eliminates the voltage drop entirely. The ATtiny can control the MOSFET gate to disconnect the supercap from the 5V rail during normal operation and connect it only during a power failure. This is more complex but more efficient.

### 4.7 Power Management Architecture (Revised for Always-On B.U.)

**Key discovery from the KRC-3006 service manual:** Pin 3 (B.U.) is Battery Unswitched — raw 12V directly from the vehicle battery through a 3A fuse, available at ALL times regardless of ignition position. The Pi can be powered whenever the truck's battery is connected, not just when the engine is running. This transforms the power management from "survive power loss" to "intelligently decide when to stay on."

**Parasitic drain budget:** A Pi 4 at idle draws ~600mA at 5V, which translates to ~250mA from the 12V battery (accounting for ~85% buck converter efficiency). Over 24 hours that's 6Ah — roughly 10% of a typical Group 78 battery (60-70Ah). The system must NOT stay on indefinitely. A mandatory maximum on-time after ignition-off prevents a dead battery.

#### ATtiny Input Signals

The ATtiny monitors TWO independent signals to determine system state:

**Signal 1: B.U. voltage via ADC**
```
VBATT_FILT ---[100kΩ]---+---[33kΩ]--- GND
                         |
                         +--- ATtiny ADC pin (PB5)
```
At 14V input: ADC reads ~3.47V. At 10V input: ADC reads ~2.48V. At 6V (deep crank): ADC reads ~1.49V. This tells us battery health and detects cranking events.

**Signal 2: Head unit protocol activity**
The ATtiny monitors CH-CON (Pin 4) and/or REQH (Pin 1) polling activity. When the head unit is on and CD changer source is selected, these signals are active. When the ignition is off and the head unit powers down, these signals go inactive. This is a clean, unambiguous digital indicator of "head unit on" vs "head unit off" — much more reliable than trying to distinguish 14.4V (charging) from 12.8V (battery resting) on the B.U. line.

#### Complete Power State Machine

| State | Entry Condition | ATtiny Behavior | Pi Behavior | Buck Converter | Max Duration |
|---|---|---|---|---|---|
| **SLEEP** | Default / after shutdown | Deep sleep (<10µA). Wake on REQH interrupt or periodic ADC sample (every ~2s). | OFF | Disabled (EN LOW) | Indefinite |
| **WAKE** | REQH activity detected OR VBATT rise from <10V to >12V | Enable buck converter. Boot immediately. Begin responding to Kenwood polls with "loading" status. | Booting | Enabled | — |
| **RUNNING** | Pi reports ready via UART | Full protocol operation. Relay commands to Pi. | Full operation: music playback, web server on AP mode. | Enabled | Indefinite (engine running) |
| **STANDBY** | Protocol polling stops (head unit off), VBATT >12V stable | Send `HU_OFF` to Pi via UART. Continue monitoring REQH for head unit return. Monitor VBATT for battery health. | Stop playback. Scan for home WiFi AP. If found → connect, enter update mode. If not found → start idle timer (60s). | Enabled | See STANDBY sub-states below |
| **UPDATE** | Pi reports home WiFi connected | Monitor VBATT. Reset idle timer on Pi activity. Send `BATT_LOW` if VBATT drops below 12.0V. | Connected to home WiFi as client. Allow SSH, file transfers, web UI access, system updates. Report activity to ATtiny to reset idle timer. | Enabled | Configurable max: 30 min default |
| **SHUTTING_DOWN** | Idle timer expired, OR `BATT_LOW` sent, OR max standby time exceeded | Wait for Pi `SHUTDOWN_ACK` or 15-second watchdog timeout. | Execute `shutdown -h now`. Send `SHUTDOWN_ACK` when halt complete. | Enabled (until ACK) | 15 seconds max |
| **POWER_OFF** | Pi halted or watchdog expired | Disable buck converter. Enter SLEEP. | OFF | Disabled → SLEEP | Immediate |
| **CRANKING** | VBATT <10V, duration <10s, was in RUNNING/STANDBY/UPDATE | Continue current operation on supercap energy. Do NOT change state. | Unaware (supercap maintains 5V). | Enabled (may drop out, supercap takes over) | 10 seconds |
| **EMERGENCY** | VBATT <10V sustained >10s, OR VBATT <9V at any time | Send `SHUTDOWN_NOW` to Pi. Force disable buck after 10s regardless. | Emergency shutdown if still responsive. | Force disabled after timeout | 10 seconds |

#### STANDBY Sub-States (Detailed)

When the head unit turns off (STANDBY state), the system follows this decision tree:

```
Head unit off detected (CH-CON inactive, no REQH polling for >2 seconds)
│
├── ATtiny sends "HU_OFF" to Pi via UART
│
├── Pi stops music playback
├── Pi scans for configured WiFi networks (5-second scan)
│
├─── Home WiFi found?
│    ├── YES → Connect to home WiFi as client
│    │         Enter UPDATE mode
│    │         Start idle timer: 30 minutes (configurable)
│    │         Reset timer on any activity:
│    │           - Active SSH session
│    │           - File transfer in progress (rsync, scp, web upload)
│    │           - Web UI page load
│    │           - System update running (apt)
│    │         On timer expiry → SHUTTING_DOWN
│    │         On max standby time (configurable, e.g., 2 hours) → SHUTTING_DOWN
│    │         On BATT_LOW from ATtiny → SHUTTING_DOWN
│    │
│    └── NO → Start short idle timer: 60 seconds
│             (Just enough for filesystem sync and clean shutdown)
│             On timer expiry → SHUTTING_DOWN
│
├─── At ANY point during STANDBY/UPDATE:
│    ├── REQH activity resumes (head unit back on) → Return to RUNNING
│    │   ATtiny sends "HU_ON" to Pi
│    │   Pi switches back to AP mode, resumes playback readiness
│    │
│    └── VBATT drops below threshold → EMERGENCY
```

#### Battery Protection Logic

The ATtiny continuously monitors battery voltage during STANDBY and UPDATE modes to prevent over-discharge:

| Battery Voltage | Condition | Action |
|---|---|---|
| >12.5V | Healthy, fully charged | Normal operation, no concern |
| 12.0V – 12.5V | Resting, adequate | Normal operation, log advisory |
| 11.5V – 12.0V | Low | ATtiny sends `BATT_LOW` to Pi. Pi begins graceful shutdown within 60 seconds. |
| <11.5V | Critically low | ATtiny sends `SHUTDOWN_NOW`. 15-second hard deadline. |
| <10V for >10s | Dead/disconnected | Emergency power off. |

**Note:** These thresholds are conservative. A healthy 12V lead-acid battery at rest reads 12.6-12.8V. Below 12.0V it's roughly 50% discharged. Below 11.5V is 20% or less — leaving enough to start the engine on a warm day but getting risky. The thresholds should be configurable via the web interface for users with different battery sizes or in different climates.

#### Maximum Standby Time Safety Net

Even with activity-based idle timer resets, there is a hard maximum standby time (configurable, default 2 hours) after which the system will shut down regardless. This prevents scenarios like: an SSH session is left connected but idle, or a file transfer stalls but the connection stays open, keeping the timer perpetually reset while the battery slowly drains overnight.

The hard maximum is the last line of defense against a dead battery.

### 4.8 ATtiny ↔ Pi UART Command Protocol

The ATtiny and Pi communicate over UART (115200 baud, 8N1). Commands are simple ASCII strings terminated with newline (`\n`). This keeps the protocol human-readable for debugging via serial monitor.

#### ATtiny → Pi Commands

| Command | Meaning | Pi Action |
|---|---|---|
| `HU_ON\n` | Head unit is active, protocol polling detected | Switch to AP mode, prepare for playback |
| `HU_OFF\n` | Head unit powered down, B.U. still live | Stop playback, scan for home WiFi, start idle logic |
| `BATT_LOW\n` | Battery voltage below 12.0V threshold | Begin graceful shutdown within 60 seconds |
| `SHUTDOWN_NOW\n` | Emergency — battery critical or sustained power loss | Execute immediate `shutdown -h now` |
| `CRANK_START\n` | Voltage dip detected (cranking event) | Optional: pause playback to reduce current draw |
| `CRANK_END\n` | Voltage recovered from cranking dip | Optional: resume playback |
| `CMD:xx xx xx\n` | Kenwood protocol command received from head unit | Parse command, execute media control (play, next, prev, disc change, etc.) |
| `VBATT:xxxx\n` | Battery voltage in millivolts (periodic, every 10s) | Display on web dashboard, log for diagnostics |

#### Pi → ATtiny Commands

| Command | Meaning | ATtiny Action |
|---|---|---|
| `READY\n` | Pi booted, Flask app running, UART link established | Transition from "loading" status to full protocol operation |
| `PLAY\n` | Playback started | Update Kenwood status to "playing", begin time counter responses |
| `STOP\n` | Playback stopped | Update Kenwood status to "stopped" |
| `TRACK:dd\n` | Current track number (decimal) | Include in Kenwood time/status responses |
| `DISC:dd\n` | Current disc number (decimal) | Include in Kenwood disc status responses |
| `TIME:mm:ss\n` | Current playback position | Include in Kenwood time poll responses |
| `MAG:bbbbbbbbbb\n` | Magazine bitmap (10 chars, '1'=disc present) | Include in Kenwood magazine status responses |
| `MUTE_ON\n` | Request mute (disc change starting) | Pull MUTE line LOW |
| `MUTE_OFF\n` | Release mute (audio ready) | Release MUTE line HIGH |
| `SHUTDOWN_ACK\n` | Pi has completed shutdown sequence | Disable buck converter, enter SLEEP |
| `WIFI_HOME\n` | Connected to home WiFi (UPDATE mode active) | Reset idle timer, allow extended standby |
| `WIFI_NONE\n` | No home WiFi found | Start short (60s) idle timer |
| `ACTIVITY\n` | User activity detected (SSH, file transfer, web UI) | Reset idle timer |

### 4.9 Power Sequencing (Revised)

**Normal start (ignition ON):**
1. Key turned → ACC energizes head unit → head unit boots → begins polling on REQH
2. ATtiny in SLEEP detects REQH interrupt → wakes → drives buck converter EN HIGH
3. Buck converter starts → 5V rail energizes → supercap begins charging
4. ATtiny boots fully (~1ms) → begins responding to Kenwood polls with "loading magazine" status
5. Pi boots from SSD (~10-15s) → Flask app starts → sends `READY` over UART
6. ATtiny transitions to RUNNING state → full protocol operation → music playback available

**Normal stop (ignition OFF):**
1. Key turned off → ACC drops → head unit powers down → REQH polling stops → CH-CON goes inactive
2. ATtiny detects 2 seconds of no polling → enters STANDBY → sends `HU_OFF` to Pi
3. Pi stops playback → scans for home WiFi (5 seconds)
4. **Home WiFi found**: Pi connects as client → sends `WIFI_HOME` → ATtiny allows extended standby (up to 2 hours). User can access Pi over home network for music management, updates, SSH.
5. **No WiFi found**: Pi sends `WIFI_NONE` → ATtiny starts 60-second idle timer → Pi syncs filesystems
6. Timer expires → ATtiny sends `BATT_LOW` or Pi's internal idle timer triggers → Pi executes `shutdown -h now` → sends `SHUTDOWN_ACK`
7. ATtiny receives ACK → disables buck converter → enters SLEEP

**Re-start while in STANDBY/UPDATE:**
1. Key turned back on while Pi is still running in standby/update mode
2. ATtiny detects REQH polling → sends `HU_ON` to Pi
3. Pi switches WiFi back to AP mode → resumes playback readiness → sends `READY`
4. Seamless transition — no reboot needed. Music available within 1-2 seconds.

**This seamless resume is a huge usability win.** If you pull into the driveway, turn the truck off, go inside for 5 minutes to grab something, and come back — the Pi is still running (connected to home WiFi), and when you start the truck, music is available instantly without a 15-second boot wait.

**Cranking event (engine restart):**
1. Starter motor engages → B.U. voltage sags to 8-9V
2. Buck converter may drop out of regulation
3. Supercap maintains 5V rail for the Pi — cranking is invisible to the software
4. ATtiny detects voltage dip via ADC → sends `CRANK_START` to Pi (informational)
5. Engine catches → voltage recovers to 14V → ATtiny sends `CRANK_END`
6. Normal operation continues — no state change, no reboot

### 4.10 Feeding 5V to the Pi via GPIO

The Pi is powered through GPIO pins 2 and 4 (5V) and pins 6, 9, etc. (GND). **This bypasses the Pi's USB-C power input and its onboard protection.** The HAT's 5V rail must be well-regulated and protected. The input protection circuit, buck converter, and supercap collectively ensure this. As a last-resort clamp, add a 5.1V Zener diode from the 5V rail to ground — if the buck converter ever overshoots (unlikely but possible during transient recovery), the Zener clamps it before it reaches the Pi.

### 4.11 Audio-Specific Power Considerations for HEI Ignition Environment

Alternator whine (a pitched whine that varies with engine RPM) is the most common audio complaint in car Pi/DAC installations, and it's worse in vehicles with older alternators. Prevention strategy:

1. **The pi-filter on the 12V input** (Section 4.3) is the first defense — it prevents conducted noise from reaching the buck converter.
2. **Separate analog and digital ground pours** on the HAT PCB, connected at a single star point near the 3.3V LDO. This prevents switching converter return currents from flowing through the DAC's ground reference.
3. **The AMS1117-3.3 LDO** between the switching 5V rail and the DAC's 3.3V supply provides an additional ~40dB of high-frequency power supply rejection.
4. **Route the PCM5102A's analog outputs (OUTL, OUTR) away from the buck converter's inductor and switching node** — these are the highest-EMI areas on the board.
5. **The audio coupling capacitors** (2.2µF in series with each output) block any DC offset, and the optional output RC filter (1kΩ + 100pF) attenuates any ultrasonic switching noise that might couple into the audio path.
6. **If alternator whine persists after all of the above**: Add the optional common-mode choke on the 12V/GND input lines, and consider a small ferrite bead (e.g., 600Ω @ 100MHz) in series with each audio output line before it reaches the DIN connector.

---

## 5. HAT PCB Mechanical Design

### Dimensions
- **Full HAT**: 65mm × 56.5mm (matches Pi 3B+ footprint)
- **Mounting holes**: 4x M2.5, matching Pi hole pattern (58mm × 49mm spacing)
- **GPIO connector**: 2×20 pin female header, positioned to align with Pi's male header
- **Corner radius**: 3mm on all corners

### KiCad Starting Point
Use the `devbisme/RPi_Hat_Template` from GitHub — includes correct outline, mounting holes, and GPIO connector footprint. Multiple forks exist with EEPROM circuitry pre-wired.

### EEPROM (Optional but Recommended)
A 24C32 I2C EEPROM on the HAT's ID_SC/ID_SD pins (GPIO 0/1) allows the Pi to auto-detect the HAT and load the correct device-tree overlay (hifiberry-dac) on boot without manual config.txt editing. This is a nice-to-have for an open-source project — makes first-time setup trivial.

### Connector Strategy for the 13-Pin DIN

The round 13-pin DIN connector itself won't mount directly on a HAT PCB. Options:
1. **Cable with pin header**: Solder a 13-pin DIN cable (from a sacrificial Kenwood changer cable) to a 2×7 or 1×14 pin header on the HAT edge. Simple, cheap, flexible.
2. **Screw terminal blocks**: 14-position 3.5mm pitch screw terminal on the HAT edge. User wires from DIN connector to terminals. More professional, easier to debug individual signals.
3. **JST-XH or Molex connector**: Keyed connector prevents miswiring. Requires a matching adapter cable.

**Recommendation**: Use a 2×7 2.54mm pin header during prototyping (easy breadboard access), then switch to a keyed JST-XH or similar for the final design. Include all 13 signal labels on the silkscreen.

---

## 6. WiFi Access Point & Web Interface

### Tri-Mode WiFi Architecture

The WiFi subsystem operates in three modes, tightly integrated with the power management state machine (Section 4.7):

| Power State | WiFi Mode | Purpose |
|---|---|---|
| RUNNING (engine on, head unit active) | **AP Mode** | Broadcast local hotspot for phone/tablet control of playback and magazine management |
| STANDBY → UPDATE (engine off, home WiFi found) | **Client Mode** | Connect to home network for music transfers, system updates, SSH access |
| STANDBY (engine off, no WiFi found) | **Off / Minimal** | WiFi can be disabled to reduce power draw during short shutdown countdown |

**Boot sequence (triggered by ATtiny `HU_ON` command or fresh boot):**
1. Pi boots, runs startup script
2. Check power state from ATtiny via UART — fresh boot (head unit on) or resume from standby?
3. If head unit active → start AP mode immediately (primary use case: in the truck, controlling from phone)
4. If resuming from standby → maintain current WiFi state

**Ignition-off transition (triggered by ATtiny `HU_OFF` command):**
1. Pi stops music playback
2. Pi switches WiFi from AP mode to client scan mode
3. Scans for configured home networks (5-second timeout)
4. If home network found → connect as client, send `WIFI_HOME` to ATtiny, enter UPDATE mode
5. If no network found → send `WIFI_NONE` to ATtiny, prepare for short-timer shutdown

**AP Mode defaults (while driving / head unit active):**
- SSID: `KRC3006-Changer` (user-configurable via web UI)
- Password: `changeme` (user must change on first setup)
- IP: `192.168.4.1`
- DHCP range: `192.168.4.10 – 192.168.4.50`
- DNS: dnsmasq serves a captive portal redirect to `http://changer.local` or `192.168.4.1`
- Channel: Auto-select least congested 2.4GHz channel

**Client Mode behavior (parked at home / UPDATE state):**
- Connect to user-configured home WiFi SSID/password
- Obtain IP via DHCP from home router
- Advertise `changer.local` via mDNS (avahi-daemon) so the user can find it on the home network
- All web UI features available over the home network
- SSH access available for advanced administration
- rsync/scp available for bulk music transfers (much faster over home WiFi than AP mode)
- The Pi 4's gigabit Ethernet port is also available if the user wants to run a cable for maximum transfer speed when loading large music libraries

**Packages needed:** `hostapd`, `dnsmasq`, `flask`, `avahi-daemon`, `wpa_supplicant`

### Web Interface (Flask Application)

**Backend: Python + Flask**
- Lightweight, runs on Pi with minimal memory/CPU overhead
- REST API endpoints for all operations
- Communicates with ATtiny over UART (pyserial)
- Controls MPD or mplayer for audio playback
- Reports activity to ATtiny (sends `ACTIVITY` command on user interaction to reset standby idle timer)

**Key pages/features:**
1. **Dashboard** — Current status: playing/stopped, disc number, track number, head unit connection status, battery voltage (from ATtiny `VBATT` reports), WiFi mode (AP/Client), power state, uptime, SSD usage
2. **Magazine Manager** — Drag-and-drop interface to assign music folders/playlists to virtual disc slots (CD01–CD10). Browse SSD storage, create playlists.
3. **Music Library** — Browse all music on the SSD. Upload new music via web UI (drag-and-drop file upload). Delete tracks. Organize into folders. Available in both AP mode (from phone in the truck) and client mode (from any device on home network).
4. **WiFi Settings** — Configure home network SSID/password for automatic standby connection. Set AP mode SSID/password. View connected clients in AP mode. Current WiFi status and signal strength.
5. **Power Settings** — Battery voltage history graph. Low-battery threshold (configurable). Maximum standby duration (default 2 hours). Short-timer duration when no WiFi found (default 60 seconds). Toggle: enable/disable WiFi standby mode entirely.
6. **Firmware Update** — Upload new ATtiny firmware (.hex file), flash via pyupdi with progress bar. System update (apt upgrade) — can be auto-scheduled during UPDATE mode standby.
7. **Protocol Debug** — Live view of Kenwood bus commands (ATtiny relays decoded commands to Pi via UART). Invaluable during development, useful for other reverse engineers contributing to the open-source project.
8. **System Settings** — Hostname, passwords, audio output config, shutdown button, reboot button, SSH enable/disable.

**Activity tracking for standby idle timer:**
The Flask app tracks user activity and sends `ACTIVITY` to the ATtiny whenever:
- Any web page is loaded (HTTP request received)
- A file upload/download is in progress
- An SSH session is active (monitored via `who` output or utmp)
- A system update (apt) is running
- An rsync/scp transfer is active (monitored via process list or network I/O)

This ensures the ATtiny's idle timer stays reset as long as anyone is actively using the system, preventing premature shutdown during a large music library transfer.

**Frontend:** Responsive HTML/CSS/JS — must work well on phone screens since primary use is controlling from a mobile device. Consider Alpine.js or vanilla JS with CSS Grid. The UI should clearly indicate the current power/WiFi state (e.g., "Connected to Home WiFi — system will sleep in 28 minutes" or "Head unit active — playing CD3 Track 7").

### mDNS / Captive Portal
Install `avahi-daemon` so the Pi advertises `changer.local` via mDNS in both AP and client modes. In AP mode, dnsmasq can redirect all DNS queries to `192.168.4.1`, creating a captive-portal experience (phone auto-opens the control page). In client mode, mDNS allows discovery via `changer.local` from any device on the home network without needing to know the DHCP-assigned IP address.

---

## 7. JLCPCB Assembly Checklist

### Design-for-Assembly Rules
- Use **0805 or larger** passives where possible (0402 may require Standard PCBA tier)
- Keep all SMD components on **one side** if using Economic assembly
- Mark **pin 1** on all ICs with a silkscreen dot
- Mark **polarity** on all diodes, LEDs, and electrolytic caps
- Verify every part has a **JLCPCB part number** (not just LCSC — they have separate stock)
- Limit **extended parts** to minimize per-part setup fees

### Critical Parts to Verify Stock Before Layout

| Component | JLCPCB Part # | Notes |
|---|---|---|
| ATtiny1616-MNR | C507118 | Confirmed available |
| PCM5102APWR | Check at order time | Has had stock issues; have backup plan |
| AMS1117-3.3 | C6186 | Basic part, always in stock |
| TPS5430DDAR | Check at order time | Or substitute MP1584EN |
| 24C32 EEPROM | C6482 (AT24C32) | For HAT auto-detection |
| Schottky SS34 | C8678 | Input protection |
| Various passives | Use basic parts | 0805 preferred |

### Files Needed for JLCPCB Order
1. **Gerber files** — Generated from KiCad (use JLCPCB's Gerber export plugin or follow their spec)
2. **BOM file** — CSV with columns: Comment, Designator, Footprint, LCSC Part #
3. **Pick-and-place file** — CSV with columns: Designator, Mid X, Mid Y, Rotation, Layer
4. KiCad can generate all three with the JLCPCB fabrication toolkit plugin

---

## 8. Development Phases (Post-Reverse-Engineering)

### Phase A: Breadboard Prototype
- ATtiny1616 on a breakout board (Adafruit sells one)
- GY-PCM5102 module on breadboard
- LM2596 buck module for power
- Validate all connections match the reverse-engineered protocol from TP-KRC3006-001

### Phase B: HAT Rev 1
- Full KiCad schematic and layout
- JLCPCB fabrication (2-layer PCB is sufficient; 4-layer preferred for cleaner power/ground)
- SMD assembly for ATtiny, DAC, power supply
- Through-hole assembly (GPIO header, connectors) by hand
- Functional test against all Phase 4 and Phase 5 test cases

### Phase C: HAT Rev 2 (if needed)
- Fix any issues found in Rev 1
- Add EEPROM if not included in Rev 1
- Optimize layout for noise/EMI
- Finalize enclosure mounting strategy

### Phase D: Software Polish
- Flask web interface feature-complete
- MPD integration with playlist management
- OTA firmware update for ATtiny
- Documentation for open-source release

---

## 9. Open Questions to Resolve During Testing

1. **ATtiny operating voltage**: Can the Kenwood bus reliably read 3.3V as HIGH? If yes, run the ATtiny at 3.3V (eliminates all level shifting). If no, run at 5V with a divider on the Pi UART line.
2. **PCM5102A JLCPCB stock**: If unavailable, switch to module-on-header or PCM5122.
3. **Audio ground isolation**: Phase 1 testing will confirm whether Kenwood pins 2 and 6 are isolated. This determines single-point ground strategy on the HAT.
4. **Pi boot time vs. Kenwood timeout**: If the head unit gives up on the changer before the Pi boots (~20s), the ATtiny must handle autonomous status responses for the first 20 seconds.
5. **UART sharing**: Can the same UART TX/RX be used for both ATtiny communication and UPDI programming (with a GPIO-controlled switch), or should a second UART/bit-banged interface be used?
6. **Thermal**: Does the buck converter need a thermal relief area or heatsink pad? Depends on efficiency at 14V→5V at 1.5A load. Calculate: Pin = 14V × 1.5A/0.9 (90% efficiency) = 2.33W, Ploss = 0.23W — should be fine without a heatsink.
7. **Kenwood Pin 3 supply path**: ~~Examine the KRC-3006 service manual schematic to confirm whether Pin 3 is raw battery voltage or has any internal filtering/regulation.~~ **RESOLVED: Confirmed raw B.U. (Battery Unswitched) through 3A fuse only. No filtering. Always-on regardless of ignition. See SA-KRC3006-001 Section 2.**
8. **Supercap sizing validation**: During Phase A breadboard testing, measure actual Pi 4 current draw during shutdown with the target OS image and SSD. If shutdown completes in <5 seconds on a stripped OS, a 10F cap may be sufficient instead of 22F, saving board space.
9. **Cranking voltage profile**: During Phase A, connect the logic analyzer or a scope to the 12V line at the Kenwood changer connector while cranking the Silverado. Record the actual voltage minimum, sag duration, and any spike transients. This is the definitive data for input protection design.
10. **Supercap diode vs. MOSFET switch**: Test whether the ~0.3V Schottky drop (cap charges to 4.7V instead of 5.0V) still provides enough holdup time. If marginal, implement the P-FET ideal diode controlled by the ATtiny.
11. **Alternator whine test**: During Phase 5 integration testing in the Silverado, listen for alternator whine at various RPMs. If present, add the common-mode choke and/or ferrite beads on audio outputs. Document which mitigation steps were necessary — this is valuable data for the open-source project since many builders will have similarly aged vehicles.
12. **Shutdown timing with warm engine vs. cold**: The cranking-vs-ignition-off timer is now based on CH-CON/REQH activity rather than voltage, so the old 10-second voltage timer concern is less relevant. However, verify that the head unit's polling stops cleanly and promptly when ignition is turned off — if the head unit has its own power holdup that keeps it polling for several seconds after ACC drops, the ATtiny's "2 seconds of no polling" detection threshold may need adjustment.
13. **ATtiny sleep current from B.U.**: Measure the total quiescent current draw of the ATtiny + buck converter (disabled) + voltage divider from the 12V rail when the system is in SLEEP state. Target is <50µA total. If the voltage divider (100K/33K = 133K total, ~100µA at 13V) dominates, consider increasing resistor values to 330K/100K (~30µA) with a small filter cap to maintain ADC accuracy. Alternatively, the ATtiny can power the divider through a GPIO pin, only enabling it during periodic ADC samples.
14. **WiFi standby power draw from battery**: Measure actual Pi 4 power draw in UPDATE mode (WiFi client, Flask running, SSD idle). Expected ~2.5-3W. Confirm the parasitic drain math: at ~250mA from the 12V battery, 2 hours of standby = 500mAh, which is <1% of the battery. Verify this is acceptable.
15. **Head unit polling cessation behavior**: When the ignition is turned off, does the KRC-3006's µ-COM stop polling immediately, or does it continue for some seconds on its own Q19 power holdup circuit? If the head unit keeps polling for 5-10 seconds after ACC drops, the ATtiny's standby detection needs to account for this delay. Capture a power-off sequence with the logic analyzer during Phase 2 to characterize this.

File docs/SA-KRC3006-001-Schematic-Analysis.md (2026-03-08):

# KRC-3006 Service Manual Schematic Analysis
## Document ID: SA-KRC3006-001 Rev B
**Date:** ___  
**Source Documents:**
- Kenwood KRC-3006 Service Manual (B51-6670-00), Schematic Y36-1740-10 — Head Unit
- Kenwood KDC-CX85/CPS85 Service Manual (B51-7552-00) — CD Auto Changer (companion unit)

---

## 1. Confirmed CD-CH Connector Pinout (from Kenwood Schematic)

The CD changer connector is part **E06-1301-05**, a 13-pin round DIN. The pin table directly from the Kenwood schematic is:

| Pin | Kenwood Name | Published Name | Function |
|-----|---|---|---|
| 1 | **REQ H** | CH-REQH | Request handshake from head unit |
| 2 | **GND** | GND | Ground |
| 3 | **B.U** | +12V | Battery Unswitched — raw +12V from vehicle battery via 3A fuse |
| 4 | **ON** | CH-CON | Changer connect / enable signal |
| 5 | **MUTE** | CH-MUTE | Mute request line |
| 6 | **D.GND** | AGND | Digital Ground (Kenwood labels this "D.GND", not "Audio GND") |
| 7 | **RESET** | CH-RST | Reset signal to changer |
| 8 | **R ch** | R-CH | Right audio channel (analog) |
| 9 | **REQ C** | CH-REQC | Request handshake from changer |
| 10  | **DATA C**  | CH-DATAC | Data from changer to head unit |
| 11  | **DATA H**  | CH-DATAH | Data from head unit to changer |
| 12  | **L ch** | L-CH | Left audio channel (analog) |
| 13  | **CLK** | CLK | 125 KHz synchronous clock |

**Notable differences from published documentation:**
- Pin 4 is labeled "ON" by Kenwood (not "CH-CON") — same function, different naming
- Pin 6 is labeled "D.GND" (Digital Ground), not "AGND" (Audio Ground) as in published pinouts. This may mean Kenwood intended a single digital ground reference, not a separate audio ground. **This must be verified during Phase 1 continuity testing** — measure resistance between Pin 2 (GND) and Pin 6 (D.GND) to determine if they are tied together or isolated on the head unit side.

---

## 2. Pin 3 (B.U) Power Path — CONFIRMED: No Head Unit Filtering

The schematic confirms the +12V supply path to Pin 3:

```
Vehicle Battery → Main Harness → E30-4119-05 DC Cord → 3A Fuse → B.U bus → Pin 3 of CD-CH connector
```

- The DC cord (E30-4119-05) carries GND, ACC (7.5A fuse), B.U (3A fuse), P.CON, and speaker wires
- B.U stands for "Battery Unswitched" — always-on +12V directly from the vehicle battery
- The 3A fuse is the ONLY protection between the vehicle battery and Pin 3
- **There is NO internal regulator, filter, inductor, TVS diode, or any other conditioning** between the fuse and Pin 3
- The B.U bus also powers IC7 (TA8232H power amplifier) at 14.4V as shown on the schematic

**Implication for HAT design:** The HAT's input protection circuit is the ONLY protection for the Pi and all electronics. The pi-filter, TVS diode, and Schottky designs in DR-KRC3006-002 are essential, not optional. On the '85 Silverado, Pin 3 will see every voltage transient, alternator ripple, and cranking sag that the vehicle battery sees, delayed only by the wire impedance and the 3A fuse.

---

## 3. Signal Routing from Connector to µ-COM

### 3.1 Digital Signal Path

All digital control and data signals route from J3 (the board-level connector for the 13-pin DIN) through series resistors to the main bus, then to IC6 (LC72329-8839 µ-COM).

**Series resistors on data/clock lines (visible on schematic):**

| Signal | Pin | Series Resistor(s) | Value | Purpose |
|---|-----|---|---|---|
| DATA H | 11  | R145 | 100K  | Current limiting on head-unit-to-changer data |
| CLK | 13  | R146 | 100K  | Current limiting on clock line |
| DATA C | 10  | R130, R131 | 2.2K each | Lower impedance for changer-to-head-unit data |
| REQ C  | 9 | (trace visible) | — | Connects through to µ-COM |
| REQ H  | 1 | (trace visible) | — | Connects through to µ-COM |

**Key observation:** The 100K series resistors on DATA H and CLK (the lines driven BY the head unit) are surprisingly high. At 5V through 100K, the maximum current is only 50µA. This suggests these lines are CMOS-level inputs on the changer side with very high input impedance, and the head unit drives them through current-limiting resistors as protection. The 2.2K resistors on DATA C (driven BY the changer back to the head unit) are much lower, allowing ~2.3mA drive current.

**Implication for emulator:** The ATtiny reading DATA H and CLK only needs to handle 50µA signal currents through 100K resistors. These signals will be slow to rise/fall due to the RC time constant of 100K × parasitic capacitance. At 125 KHz, the period is 8µs — with even 20pF of parasitic capacitance, τ = 100K × 20pF = 2µs, which is 25% of the clock period. **This may explain why some emulator projects have had timing issues** — the signal edges are significantly rounded by these series resistors.

### 3.2 Mute Control (Pin 5)

Pin 5 (MUTE) is controlled by **Q12**, labeled "CD-CH MUTE SW":
- Q12 is a transistor switch (DTC114YK — NPN digital transistor with built-in bias resistors)
- Driven from the µ-COM IC6
- External components: R140 (7.5K), 10K, 47K resistors; C103 (0.01µF) for noise filtering
- When the µ-COM drives Q12, it pulls MUTE low, requesting the head unit to mute audio output
- During disc changes or error conditions, the changer would pull this line

**For emulator:** The ATtiny should drive MUTE low during virtual disc changes (switching between music folders) to prevent audio pops/clicks during the transition. A brief 200-500ms mute during folder changes would be appropriate.

### 3.3 Reset Control (Pin 7)

Pin 7 (RESET) is controlled by **Q13**, labeled "CD-CH RESET SW":
- Q13 is a transistor switch (DTA114EK — PNP digital transistor with built-in bias resistors)
- Driven from the µ-COM IC6
- 22K/22K resistor pair for biasing
- The head unit sends a reset pulse to the changer on power-up or error recovery

**For emulator:** The ATtiny should monitor RESET (Pin 7) as an input. When RESET is asserted by the head unit, the ATtiny should reinitialize its protocol state machine and restart the handshake sequence. This is equivalent to a "reboot" command for the changer emulation.

### 3.4 µ-COM Hold Switch (Q19)

**Q19** is labeled "µ-COM HOLD SW" with 47K/47K resistors and C109 (0.1µF):
- This is a power hold circuit that keeps the µ-COM energized during brief power interruptions
- Connected through R150 (4.7K) and C74 (4.7µF, 35V)
- Likely provides a few hundred milliseconds of power hold-up for the µ-COM itself during cranking

**Implication:** Even Kenwood's own design includes a power holdup mechanism for the µ-COM during cranking. This validates our supercap approach for the Pi — if Kenwood needed it for a simple microcontroller, we definitely need it for a full Linux SBC.

---

## 4. Audio Path Analysis

### 4.1 Audio Signal Flow

```
CD-CH Pin 8 (R ch) → CN5 (CH R) → Sub-board X13-8570-10 → R12 (1K) → R18 (47K) → C12 (1µF/50V) → IC3 Pin 7
CD-CH Pin 12 (L ch) → CN5 (CH L) → Sub-board X13-8570-10 → R11 (1K) → R17 (47K) → C11 (1µF/50V) → IC3 Pin 2
CD-CH Pin 6 (D.GND) → CN5 (CH GND) → Sub-board ground reference
```

### 4.2 IC3 — Audio Isolation Amplifier

**IC3: NJM4565MD** (JRC dual op-amp)
- Configured as an isolation/buffer amplifier for CD changer audio
- Powered from 8.0V on pin 8 (+B), with 5.1V bias points on signal pins
- Input coupling: 1K series resistor + 47K to bias + 1µF DC-blocking capacitor per channel
- Output coupling: 680Ω resistors (R28/R27) to the main audio bus, then through 100µF/10V electrolytic caps (C16/C15) to the selector (IC2, TC4066BF)

**Input impedance seen by the changer:** The 1K series resistor and 47K to bias create an input impedance of approximately 1K + 47K = 48K ohms. The 1µF coupling caps (C12, C11) provide a low-frequency cutoff of approximately 1/(2π × 48K × 1µF) ≈ 3.3 Hz — essentially passing all audio frequencies.

### 4.3 IC2 — Audio Selector (TC4066BF)

**IC2: TC4066BF** (CMOS bilateral switch)
- Selects between audio sources: CD changer, tape, FM, AM
- Controlled by the µ-COM IC6 via CH-CON and source selection signals
- The µ-COM must assert CH-CON (Pin 4 "ON") AND complete the digital handshake before IC2 routes the CD changer audio to the preamp/tone/power amp chain

**Critical implication:** Audio from the DAC will NOT reach the speakers until BOTH conditions are met:
1. Pin 4 (ON/CH-CON) is asserted by the head unit (confirming CD changer source is selected)
2. The digital protocol handshake succeeds (the µ-COM must recognize a valid changer before enabling the audio path through IC2)

This confirms what the initial research document stated — there is no "audio only" shortcut. Full protocol emulation is mandatory.

### 4.4 Audio Levels

The preout level specification from the service manual back cover:
- **Preout Level/Load: 1000mV (MAX.) / 10kΩ**

The CD changer audio input goes through IC3 (gain to be determined from feedback resistors), then through IC2 (unity gain switch), then to the preamp/tone circuits. The PCM5102A DAC outputs approximately 1V RMS at full scale. With the 1K/47K input network, the signal reaching IC3 is essentially the full DAC output voltage. This should be a good match — possibly even slightly hot depending on IC3's gain setting.

**During Phase 5 testing:** If the audio is too loud or distorted when the Pi plays at full volume through the DAC, reduce the DAC output level in software (ALSA mixer or MPD volume control) rather than adding hardware attenuation. The NJM4565 has plenty of headroom.

---

## 5. Power Supply Architecture (Internal)

### 5.1 Voltage Rails Identified on Schematic

| Rail | Voltage | Source | Consumers |
|---|---|---|---|
| B.U  | 14.4V (nominal) | Vehicle battery via 3A fuse | IC7 power amp, CD-CH Pin 3 |
| ACC  | 14.4V (switched) | Vehicle ignition via 7.5A fuse | Main power control |
| 8.0V | 8.0V regulated | Internal AVR (Q2,7 "8V AVR") | IC3 (audio isolation amp), IC5 (FM MPX) |
| 5.1V | 5.1V regulated | Internal 5V AVR (R99, Q6) | IC6 µ-COM, digital circuits |
| 5.0V | 5.0V regulated | "5V AVR" circuit | Logic ICs |

### 5.2 IC6 µ-COM Operating Voltage

The LC72329-8839 µ-COM operates at **5.0V** (from the internal 5V AVR). The schematic shows pin voltages on IC6 in the 4.9V-5.4V range. This confirms:
- All digital signals on the CD changer bus are **5V logic levels**
- The bus protocol uses 5V TTL/CMOS signaling
- Running the ATtiny1616 at 5V is the safest approach for direct bus compatibility
- Running at 3.3V would require confirming the head unit reads 3.3V as a valid HIGH through the 2.2K series resistors on DATA C

---

## 6. Key Components Summary

| Ref | Part Number | Function | Relevance |
|-----|---|---|---|
| IC6 | LC72329-8839 | µ-COM (main microcontroller) | Generates all CD changer protocol commands; processes responses |
| IC3 | NJM4565MD | Dual op-amp (audio isolation) | Buffers CD changer audio before routing to selector |
| IC2 | TC4066BF | CMOS bilateral switch (audio selector) | Routes selected source (CD-CH, tape, FM, AM) to output |
| IC7 | TA8232H | Dual power amplifier | Drives speakers; powered from B.U (14.4V) |
| Q12 | DTC114YK | CD-CH MUTE SW | Transistor switch for mute control line |
| Q13 | DTA114EK | CD-CH RESET SW | Transistor switch for reset control line |
| Q19 | — | µ-COM HOLD SW | Power hold for µ-COM during brief interruptions |
| J3  | — | 13-pin connector (board side) | Board-level connection to CD-CH DIN connector |
| CN5 | — | Audio connector to sub-board | Routes CH R, CH GND, CH L, CH CON to IC3 |

---

## 7. Findings That Affect Emulator Design

### 7.1 Pin 3 is Raw Battery Voltage — Confirmed
No filtering whatsoever between vehicle battery and the changer connector power pin. The HAT's input protection is the sole defense. Design accordingly with the pi-filter, TVS, and Schottky protection detailed in DR-KRC3006-002.

### 7.2 High-Value Series Resistors on Clock and Data Lines
The 100K resistors on DATA H (R145) and CLK (R146) will significantly affect signal rise/fall times. During logic analyzer capture in Phase 2, expect to see rounded edges rather than sharp square waves. This is normal — the protocol was designed for this impedance. The ATtiny's Schmitt-trigger inputs will clean up these edges nicely.

### 7.3 Audio Path Requires Full Protocol Handshake
The TC4066BF bilateral switch (IC2) won't route audio until the µ-COM activates it via the CH-CON signal AND validates the changer protocol. No shortcut possible.

### 7.4 Pin 6 (D.GND) May Not Be Isolated
Kenwood labels Pin 6 as "Digital Ground" not "Audio Ground." It may be tied to Pin 2 (GND) internally. Phase 1 continuity testing will resolve this. If they ARE tied together, the separate ground strategy on the HAT is still valuable (prevents ground loops from the vehicle wiring), but the HAT can use a single ground connection to Pin 2/6.

### 7.5 Mute Line Is Active for Disc Changes
Q12 shows the head unit has a dedicated mute switch circuit for the CD changer. The emulator should pull MUTE low for 200-500ms during virtual disc changes to suppress clicks/pops.

### 7.6 µ-COM Has Its Own Power Holdup
Q19 (µ-COM HOLD SW) confirms that even Kenwood's engineers found it necessary to hold the µ-COM through brief power interruptions. This further validates the supercap approach for the Pi.

### 7.7 Operating Voltage Confirmed at 5V
The µ-COM runs at 5.0-5.1V. All bus signals are 5V logic. For maximum compatibility and signal integrity, run the ATtiny1616 at 5V with a voltage divider on the UART TX to the Pi (3.3V).

---

## 8. Recommended Updates to Test Procedure (TP-KRC3006-001)

Based on these schematic findings, add the following to Phase 1:

1. **Measure Pin 2 to Pin 6 resistance** with the head unit unpowered (just measure the connector). If <1Ω, they're tied together internally. Record this on the test log.

2. **Measure Pin 3 voltage while toggling sources** — Pin 3 (B.U) should show constant ~12V regardless of source selection (it's unswitched). Pin 4 (ON) should toggle with source. This confirms the schematic.

3. **Check for 100K series resistance on CLK and DATA H** — With head unit unpowered, measure resistance between Pin 13 (CLK) and Pin 2 (GND). If you read ~100K, that confirms R146 is in series. Same for Pin 11 (DATA H) and R145. This is important for understanding signal levels during emulation.

4. **During Phase 2 idle capture**, look for signal rise times of 1-3µs on CLK and DATA H due to the 100K series resistors. If edges are very slow, reduce the PulseView sample rate threshold for edge detection, or use the analog channels if your logic analyzer supports them.

---

# PART 2: KDC-CX85 CD Changer Analysis (Changer-Side View)

The following sections are derived from the KDC-CX85/CPS85 service manual — the actual 10-disc CD changer that ships with the KRC-3006. This gives us the mirror image of the protocol: what the changer firmware does internally is exactly what our emulator must replicate.

---

## 9. Changer Architecture Overview

The KDC-CX85 uses a dual-processor architecture:

| IC | Part Number | Role | Relevance |
|----|---|---|---|
| IC1 | **UPD78058GCB82T** | I/F µ-COM (Interface Microcontroller) | Handles ALL communication with the head unit and optional second changer. This is the IC whose behavior we are emulating. |
| IC7 | **UPD784214GC066** | System µ-COM (CD Player Controller) | Controls the CD mechanism, laser, servo, DSP, DAC. Not relevant to emulation except for understanding status responses. |
| IC2 | PST9137NR | Reset IC | Generates system reset on power-up |
| IC6 | KKZ05F | D.R.I.V.E. DAC/Digital Filter | Audio processing — our PCM5102A replaces this function |
| IC1 (audio) | NJM5532MD | Output active filter / LPF | Analog audio output filtering |

**Key insight:** The communication with the head unit is entirely handled by IC1 (I/F µ-COM). The system µ-COM (IC7) handles CD mechanics and audio. In our emulator, the ATtiny1616 replaces IC1, and the Raspberry Pi replaces IC7 + the entire CD mechanism + DAC chain.

---

## 10. I/F µ-COM (IC1) — Complete Pin Mapping for H/U Communication

The UPD78058GCB82T is an 80-pin NEC µ-COM. The following pins handle head unit communication (from the service manual's terminal description table):

### 10.1 Head Unit Communication Pins (Primary — what we emulate)

| IC1 Pin | Pin Name | I/O | Signal | Description |
|---|---|-----|---|---|
| 11 | P20/SI1 | **Input** | DATAH0 | Data input FROM head unit |
| 12 | P21/SO1 | **Output** | DATAC0 | Data output TO head unit |
| 13 | P22/SCK1 | **I/O** | HCLK0 | Communication clock — bidirectional |
| 14 | P23/STB | **Output** | REQC0 | Communication request TO head unit — **L: Request** |
| 64 | P03/INTP3 | **Input** | REQH0 | Communication request FROM head unit — **L: Request** |
| 66 | P05/INTP5 | **Input** | CHCON1 | CH1 control input from H/U — **L: Control on** |

**Critical observations:**

1. **HCLK0 (Pin 13) is I/O** — connected to the NEC µ-COM's SCK1 (SPI clock) pin. This means the clock can be driven by either side. The NEC's SPI peripheral can operate in both master and slave modes. During head-unit-initiated transfers, the head unit drives the clock and the changer's SPI operates in slave mode. During changer-initiated transfers (e.g., spontaneous status updates), the changer may drive the clock in master mode.

2. **REQH0 is on an interrupt pin (INTP3)** — Pin 64 is P03/INTP3, a dedicated external interrupt input. This means the changer responds to head unit requests via hardware interrupt, not polling. The ATtiny1616 should similarly use an external interrupt on the REQH input for fast response.

3. **REQC0 is on the STB (strobe) pin** — Pin 14 (P23/STB) is the SPI strobe output. In the NEC architecture, STB asserts automatically during SPI transfers. This means REQC may be hardware-managed during data exchange rather than manually toggled by firmware. Our ATtiny firmware should toggle REQC in coordination with data transmission.

4. **CHCON1 is active LOW** — "L: Control on CH1." This is the opposite polarity from what some published documentation claims. The head unit pulls this line LOW to activate the changer, not HIGH. **Verify during Phase 1 testing** by measuring Pin 4 voltage when CD changer source is selected vs. another source.

### 10.2 Second Changer / AUX Cascade Pins (Not needed for emulator)

| IC1 Pin | Signal | Description |
|---|---|---|
| 8 | DATAC1 | Data input from second changer (CH1 port) |
| 9 | DATAH1 | Data output to second changer |
| 10 | HCLK1 | Clock to/from second changer |
| 6 | REQH1 | Request output to second changer |
| 65 | REQC1 | Request input from second changer |
| 15 | REQH2 | Request output to third device (CH2 port) |
| 16-18 | DATAC2/DATAH2/HCLK2 | Data/clock for CH2 port |
| 61 | REQC2 | Request input from CH2 |
| 19-20 | CHCONO1/CHCONO2 | Control outputs to CH1/CH2 |

The CX85 acts as a hub — it can cascade communication to a second changer (CH2) or AUX device. Our emulator only needs to handle the J1 "to H.U" side (DATAH0/DATAC0/HCLK0/REQH0/REQC0). The cascade functionality is irrelevant.

### 10.3 Power Management Pins

| IC1 Pin | Signal | I/O | Description |
|---|---|-----|---|
| 62 | BUDET | **Input** | BU instant dip detection — **H: BU dip detected** |
| 23 | MSTOP | **Output** | BU instant dip detection output to CH1 — **H: BU dip** |
| 63 | AUX SW | **Input** | External input switch — H: External input active |

**BUDET (Pin 62)** is the cranking/brownout detection input. When vehicle battery voltage dips during cranking, external circuitry detects the dip and drives BUDET HIGH. The I/F µ-COM then outputs MSTOP to tell the system µ-COM to halt disc operations (motor stop) to reduce current draw during the voltage sag. This is exactly analogous to our ATtiny's ADC-based voltage monitoring described in DR-KRC3006-002 Section 4.7.

### 10.4 Protocol Variant Switch (COMMSW)

| IC1 Pin | Signal | I/O | Description |
|---|---|-----|---|
| 67 | COMMSW | **Input** | 5-line communication old/new selection — **H: New, L: Old** |

**This is a critical discovery.** The COMMSW pin selects between two protocol variants:

- **Old communication (COMMSW = LOW)**: Used with older head units like the KRC-3006 (round 13-pin DIN connector, pre-1998). This is the "O protocol" referenced in Mictronics documentation.
- **New communication (COMMSW = HIGH)**: Used with newer head units (rectangular connector, post-1998). This is the "C protocol."

The System µ-COM (IC7) also has a COMMSW pin (Pin 19) with identical description, confirming both processors must agree on the protocol variant.

**For our emulator:** We are implementing the **Old (O) protocol** exclusively, since the KRC-3006 is a 1994 head unit with the round DIN connector. The COMMSW pin tells us the changer hardware-selects the protocol, meaning the differences between O and C protocol are in the data encoding/command set, not in the electrical signaling.

**Action item for testing:** When you have the CX85 changer on the bench, check the COMMSW state. Trace pin 67 of IC1 on the X13-9790-00 sub-circuit board — it likely goes to a pull-down resistor (selecting Old protocol by default) or to the COMMSW line on the CN1/CN2 connector where the head unit can set it. If COMMSW is hardwired LOW on the board, it confirms the CX85 always uses O protocol when connected to an old-style head unit.

---

## 11. System µ-COM (IC7) — Changer-Side Status Signals

The UPD784214GC066 (IC7) manages the CD mechanism. Its communication pins relevant to the emulator:

| IC7 Pin | Signal | I/O | Description |
|---|---|-----|---|
| 40 | DATAH | **Input** | Data input from H/U (routed through IC1) |
| 41 | DATAC | **Output** | Data output to H/U (routed through IC1) |
| 42 | HCLK | **I/O** | Communication clock |
| 43 | REQC | **Output** | Communication request to H/U |
| 83 | REQH | **Input** | Communication request from H/U |
| 44 | CHMUTE | **Output** | Audio mute output to H/U — **L: Mute ON** |
| 35 | AMUTE | **Output** | Internal audio mute (to DAC chain) |
| 21 | CHCON | **Input** | Changer control from H/U |
| 22 | BUDET | **Input** | BU instant dip detection |
| 19 | COMMSW | **Input** | Old/New protocol selection |
| 99 | PON | **Output** | Power ON control — **L: AVR power ON** |

### 11.1 Mute Signal Confirmation

**CHMUTE (IC7 Pin 44) — "Audio mute output to H/U — L: Mute ON"**

This definitively confirms:
- The MUTE line (Pin 5 on the 13-pin DIN) is driven by the **changer**, not the head unit
- It is **active LOW** — pull LOW to mute, release HIGH (or high-Z) to unmute
- The head unit's Q12 (CD-CH MUTE SW) circuit on the KRC-3006 schematic is the receiving end, not the driving end

**Emulator implementation:** The ATtiny should:
1. Hold MUTE HIGH (or floating with pull-up) during normal playback
2. Pull MUTE LOW ~100ms before a virtual disc change begins
3. Keep MUTE LOW throughout the disc change transition (~200-500ms)
4. Release MUTE HIGH ~100ms after the new track begins playing
5. Pull MUTE LOW during power-up initialization until the protocol handshake succeeds and audio playback is ready

### 11.2 Power ON Sequence

**PON (IC7 Pin 99) — "PON output — L: AVR power ON"**

The system µ-COM controls its own power regulator via the PON pin. When the µ-COM decides to power down (e.g., after the head unit deselects the changer), it drives PON HIGH to shut off the voltage regulator. This is directly analogous to our ATtiny controlling the buck converter's enable pin in the graceful shutdown sequence.

---

## 12. Series Resistor Cross-Reference: Head Unit vs. Changer

Both service manuals now allow us to see the complete impedance picture for each signal line — from driver through series resistors on both sides to receiver.

### 12.1 Head-Unit-to-Changer Direction

```
KRC-3006 IC6 (µ-COM) → [R145: 100K] → Pin 11 (DATA H) → cable → CX85 IC1 Pin 11 ← [R24: 100K]
KRC-3006 IC6 (µ-COM) → [R146: 100K] → Pin 13 (CLK)    → cable → CX85 IC1 Pin 13 ← [R25: 100K]
KRC-3006 IC6 (µ-COM) → [direct?]    → Pin 1 (REQ H)   → cable → CX85 IC1 Pin 64 ← [R34: 100K]
```

**Total series resistance on DATA H and CLK: ~200K** (100K on each end). At 5V, signal current is only ~25µA. The cable capacitance and input pin capacitance form an RC filter with these resistors, further explaining why signal edges will be slow. With even 30pF total capacitance, τ = 200K × 30pF = 6µs — which is 75% of the 8µs clock period at 125 KHz. This means the signals may barely reach full swing before the next transition.

**Implication:** The actual protocol may operate slower than 125 KHz due to these RC time constants, or the voltage thresholds may be set to trigger well before signals reach full 5V/0V levels. Your Phase 2 logic analyzer captures will reveal the actual waveform shape and timing. Use the analog view in PulseView if available to see the actual voltage levels, not just the digital interpretation.

### 12.2 Changer-to-Head-Unit Direction

```
CX85 IC1 Pin 12 (DATAC0) → [R28: 1K] → Pin 10 (DATA C) → cable → KRC-3006 → [R130/R131: 2.2K each]
CX85 IC1 Pin 14 (REQC0)  → [R30: 1K] → Pin 9 (REQ C)   → cable → KRC-3006 → [series R]
```

**Total series resistance on DATA C: ~5.4K** (1K + 2×2.2K). Much lower than the other direction, allowing faster edges and higher signal current (~1mA). This asymmetry makes sense — the changer's responses need to be crisp for the head unit to read reliably.

**Emulator implication:** When the ATtiny drives DATA C and REQ C, it's driving through relatively low impedance. No special drive considerations needed — standard GPIO push-pull output is ideal.

### 12.3 Complete Signal Impedance Summary

| Signal | Direction | Driver-Side R | Receiver-Side R | Total R | Max Current | Edge Speed |
|---|---|---|---|---|---|---|
| DATA H (Pin 11) | H/U → Changer | 100K | 100K | 200K | ~25µA | Very slow |
| CLK (Pin 13) | H/U → Changer | 100K | 100K | 200K | ~25µA | Very slow |
| REQ H (Pin 1) | H/U → Changer | TBD | 100K | ≥100K | ~50µA | Slow |
| DATA C (Pin 10) | Changer → H/U | 1K | 2×2.2K | ~5.4K | ~1mA | Fast |
| REQ C (Pin 9) | Changer → H/U | 1K | TBD | ~1K+ | ~5mA max | Fast |
| MUTE (Pin 5) | Changer → H/U | varies | varies | TBD | TBD | N/A (DC) |
| ON/CHCON (Pin 4) | H/U → Changer | TBD | TBD | TBD | TBD | N/A (DC) |
| RESET (Pin 7) | H/U → Changer | TBD | TBD | TBD | TBD | N/A (pulse) |

---

## 13. Changer Power Supply and Supercap

### 13.1 Power Input

The CX85's power cord (E30-4138-05) brings BU+14V directly from the head unit's Pin 3 (which we confirmed in Section 2 is raw battery voltage through a 3A fuse). The changer has its own internal regulation:

| Rail | Source | Components |
|---|---|---|
| BU14V | Raw battery input | Direct from connector, shared bus |
| S8V (Servo 8V) | Regulated from BU14V | 8V AVR circuit, switchable to 7V via IC7 Pin 92 |
| +5V | Regulated from BU14V | IC3 (TA78L05F, 100mA LDO regulator) |
| BU5V | Regulated 5V for I/F µ-COM | Separate 5V AVR circuit |
| DA5V | Regulated 5V for DAC | Separate regulator for audio DAC |
| D5V (DSP 5V) | Regulated 5V for DSP | Via IC10 area |
| M5V | Motor 5V | Motor drive supply |

**The changer has FIVE separate 5V rails** — BU5V, +5V, DA5V, D5V, and M5V — all isolated from each other. This extreme supply isolation is how Kenwood achieves 110dB S/N ratio and 96dB dynamic range. Our HAT design's separate 3.3V LDO for the DAC follows the same principle, just less aggressively.

### 13.2 Supercapacitor in the CX85

**Part C1: C90-2945-05 — Electrolytic 0.047F (47,000µF) 5.5V**

This is located in the mechanism assembly (reference 1A on the exploded view), suggesting it's on the main power input path. At 47mF charged to 5V:
- Stored energy: ½ × 0.047 × 25 = 0.59 joules
- At 100mA draw (typical µ-COM idle): holds voltage for ~0.047 × 0.4V / 0.1A = 0.19 seconds

This is enough for the microcontrollers to detect the power loss, save state to EEPROM (the CX85 has an AK93C45AF EEPROM), and halt gracefully — but NOT enough to keep the CD mechanism running. Kenwood's strategy: detect the dip, stop the motor immediately (MSTOP signal), save state, ride it out on the supercap, then resume when power returns.

**Our emulator's 22F supercap provides ~470× more energy** than Kenwood's original design, but we need it because the Pi draws ~100× more current than the changer's µ-COMs and takes ~100× longer to shut down.

### 13.3 BUDET — Battery Dip Detection Circuit

The CX85 schematic (page 11) shows the BUDET circuit:
- R46 (100K) and R47 (10K) form a voltage divider from BU14V
- R48 (18K) and C7 (0.1µF) provide filtering
- R44 (100K) and R45 (1K) set the threshold
- The resulting signal goes to IC1 Pin 62 (BUDET) and IC7 Pin 22 (BUDET)

The divider ratio of 100K/(100K+10K) ≈ 0.91 means at 14.4V nominal, the BUDET pin sees ~13.1V — but this is a 5V µ-COM, so there must be clamping. The additional resistors and cap form a filtered threshold detector. When BU14V drops below approximately 10-11V, BUDET transitions to indicate a dip.

**This matches our ATtiny design** in DR-KRC3006-002 Section 4.7, where we use a 100K/33K divider to monitor the 12V input via the ATtiny's ADC. The Kenwood engineers chose a similar approach with discrete components to create a binary threshold, while our ADC-based approach gives us more flexibility to measure the actual voltage level.

---

## 14. Protocol Variant Identification Strategy

The COMMSW discovery gives us a clear strategy for determining which protocol variant the KRC-3006 uses:

### Method 1: Check COMMSW on the CX85 Board (Easiest)

1. Locate IC1 Pin 67 on the X13-9790-00 sub-circuit board
2. Trace the pin to its external circuit — look for a pull-up or pull-down resistor
3. If pulled LOW via resistor to GND → Old (O) protocol is hardwired
4. If pulled HIGH via resistor to VCC → New (C) protocol is hardwired
5. If connected to a connector pin or solder jumper → protocol is selectable by the head unit

### Method 2: Check COMMSW on Head Unit Bus (During Phase 1)

The COMMSW signal may be one of the unnamed or dual-purpose pins on the 13-pin DIN connector. Check the head unit schematic for any output that could drive a protocol selection signal to the changer. If no such signal exists on the connector, the changer must self-select.

### Method 3: Compare Captured Messages (During Phase 2)

Capture the idle polling messages from the KRC-3006 and compare byte patterns against both the documented O-protocol and C-protocol command tables. The initialization sequence should be distinguishable between the two variants.

**Expected result:** The KRC-3006 (1994, round DIN) almost certainly uses O protocol. The COMMSW pin on the CX85 is likely either pulled LOW by default or driven LOW when connected to an old-style head unit.

---

## 15. Relay Switching Architecture (Reference Only)

The CX85 has four relays (K1-K4) that switch between three possible signal paths:

| State | K1/K2 | K3/K4 | Audio Path | Data Path |
|---|---|---|---|---|
| Normal (CH1) | De-energized | De-energized | CX85 audio → H/U | H/U ↔ CX85 directly |
| CH2 Cascade | Energized | De-energized | CH2 audio → H/U | H/U ↔ CH2 via CX85 |
| AUX Input | De-energized | Energized | AUX audio → H/U | N/A (analog only) |

The S1 switch on the X13-9790-00 board selects AUX ON/OFF. This entire relay architecture exists because the CX85 acts as a hub between the head unit and additional devices. 

**For our emulator: None of this relay logic is needed.** We connect directly to the head unit's 13-pin DIN and handle all communication and audio in one device. The relay section is irrelevant.

---

## 16. Updated Emulator Design Implications (Changer-Side Findings)

### 16.1 CHCON is Active LOW (Corrected)
The CX85 service manual states CHCON1 "L: Control on CH1." This means Pin 4 (ON/CH-CON) is pulled LOW by the head unit to activate the changer, not HIGH as some published documentation suggests. **Phase 1 testing must verify this** — measure Pin 4 when CD changer source is selected. If it reads LOW (~0V) when changer is selected and HIGH (~5V) on other sources, the CX85 documentation is correct and published pinouts are wrong on the polarity.

**Note:** This could also be an inversion at the receiving end — the CX85 may have an inverting buffer on the CHCON input. The Phase 1 measurement from the head unit side will be the definitive answer for our emulator.

### 16.2 Clock Is Bidirectional — Emulator Must Handle Both Modes
HCLK0 on the NEC µ-COM is mapped to the SPI SCK pin (SCK1), configured as I/O. The ATtiny1616's SPI peripheral can also operate in master or slave mode. During Phase 2 idle captures, watch carefully whether the clock is always driven by the head unit, or if there are scenarios where the changer side would need to drive it. If the clock is always head-unit-driven, the emulator can operate in SPI slave mode exclusively, simplifying the firmware.

### 16.3 Use Hardware Interrupts for REQ H
The CX85 maps REQH0 to INTP3 (a dedicated external interrupt). The ATtiny1616 should use a pin-change or external interrupt on the REQH input for immediate response. Do not poll this signal — interrupt-driven response is essential for meeting the tight timing requirements.

### 16.4 Mute Protocol Is Active-LOW, Changer-Driven
Confirmed from IC7 Pin 44 description. The ATtiny must actively drive MUTE LOW during disc changes and power-up, and release it HIGH when audio is ready.

### 16.5 Battery Dip Detection Is Built Into the Kenwood Protocol
The BUDET/MSTOP signals prove that the Kenwood protocol explicitly accounts for battery voltage dips. The head unit may expect or tolerate brief communication pauses during cranking. This is good news — our ATtiny can pause protocol responses during a detected voltage dip without the head unit necessarily dropping the changer connection.

### 16.6 Kenwood Used Five Separate 5V Rails for Audio Quality
The CX85's aggressive supply isolation (BU5V, +5V, DA5V, D5V, M5V) explains the 110dB S/N spec. Our simpler two-rail approach (5V for Pi/ATtiny, separate 3.3V LDO for DAC) should still achieve very good audio quality for a car environment, but if audio noise is an issue during testing, consider adding a dedicated LC filter between the 5V rail and the DAC's 3.3V LDO input.

---

## 17. Updated Test Procedure Recommendations

In addition to the Phase 1 updates in Section 8, add the following based on changer-side findings:

### Phase 1 Additions:

5. **Verify Pin 4 (ON/CHCON) polarity** — Is it HIGH or LOW when CD changer source is selected? The CX85 manual says active LOW. Published docs often say active HIGH. Only one is correct for the KRC-3006. Record the actual voltage in both states.

6. **If you have the CX85 changer available**, locate COMMSW (IC1 Pin 67) on the X13-9790-00 sub-circuit board and check whether it's pulled HIGH or LOW. This identifies the protocol variant without any protocol capture needed.

### Phase 2 Additions:

5. **Watch for clock direction changes** — In PulseView, observe whether the CLK line (CH0) is always driven from the same side, or if it switches between H/U-driven and changer-driven at different times. If only H/U-driven during idle polling (expected), note this.

6. **Capture a power-cycle sequence** — Turn the head unit off and back on while capturing. The first few hundred milliseconds after power-on will show the initialization sequence, including any RESET pulse on Pin 7. Record how quickly the first polling message appears after power-on.

### Phase 3 Additions:

7. **Test MUTE line behavior** — When the Arduino successfully handshakes, try pulling MUTE LOW and HIGH and observe if the head unit mutes/unmutes the speaker output. This verifies the MUTE line polarity and function before integration.

8. **Test with CHCON LOW expectation** — If Phase 1 confirms CHCON is active LOW, ensure the Arduino firmware checks for Pin 4 LOW (not HIGH) as the precondition for entering active protocol mode.

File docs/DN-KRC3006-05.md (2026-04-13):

# DN-KRC3006-05 — Web Application Design for Emulator Library Management

| | |
|---|---|
| **Project** | Kenwood KRC-3006 CD Changer Emulator |
| **Document type** | Design Note |
| **Status** | Draft |
| **Revision** | - |
| **Date** | 2026-03-25 |
| **Dependencies** | DN-KRC3006-01 (HAT design, UART protocol); core changer protocol must be captured first |

---

## 1. Purpose & Scope

This document defines the architecture, technology stack, and design rationale for the web application component of the CD changer emulator. The web app runs on the Raspberry Pi 5 and provides a browser-based interface for managing the music library, creating playlists, and loading virtual magazines. It does **not** control playback — all playback commands originate exclusively from the KRC-3006 head unit.

### 1.1 What the Web App Does

- **Track library management** — Browse, search, and organize a FLAC music library with an iTunes-like interface (artist, album, genre views).
- **Playlist creation** — Create, edit, save, and delete playlists from the track library.
- **Virtual magazine loading** — Assign playlists to virtual disc slots in a magazine. Save and swap magazines.
- **Library scanning** — Automatically detect and ingest new music added to the NVMe SSD.
- **System status** — Display current playback state, disc/track numbers, battery voltage, WiFi mode, and power state (read-only; informational, not interactive).

### 1.2 What the Web App Does Not Do

- **No playback controls.** No play, pause, skip, or seek buttons in the UI. The head unit is the sole playback controller.
- **No filesystem-level disc management.** Users never manually move files into numbered folders. The database and magazine abstraction handle all mapping.
- **No multi-format support.** The library ingests FLAC files only. CUE+BIN or other image formats must be converted to individual FLAC files externally before import (see Section 8).

### 1.3 Primary Use Context

The primary interaction device is a **smartphone or tablet**. The UI must be mobile-first and touch-friendly. Desktop use is secondary (bulk library management from a laptop at home).

### 1.4 Target Hardware

- Raspberry Pi 5 with 1 TB NVMe SSD
- Thermal management via DVFS; optional underclocking in `/boot/firmware/config.txt` (`arm_freq=1800`, `arm_freq_min=500`) for automotive thermal margin
- Active cooler sufficient for this workload (audio decoding + web serving barely loads the A76 cores)

---

## 2. Head Unit Command Set & Display Constraints

The KRC-3006 is a shaft-style cassette receiver. Its CD changer controls and display capabilities constrain what the emulator can present to the user through the head unit.
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

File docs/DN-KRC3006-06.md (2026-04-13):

# DN-KRC3006-06 — Kenwood CD Changer Error Codes

| | |
|---|---|
| **Project** | Kenwood KRC-3006 CD Changer Emulator |
| **Document type** | Design Note |
| **Status** | Complete |
| **Revision** | 0.1 |
| **Date** | 2026-04-13 |

---

## 1. Purpose

This document records the known error codes used by Kenwood CD changers when communicating with compatible head units over the 13-pin mini DIN interface. These codes are displayed on the head unit (e.g., KRC-3006) but originate from the changer hardware — the head unit simply renders whatever status the changer reports over the serial data bus.

Understanding these codes is relevant to the emulator project in two ways: (1) we may need to replicate error status reporting in the emulator firmware, and (2) they informed the diagnosis of the original KDC-CX85 changer used in early project phases.

---
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

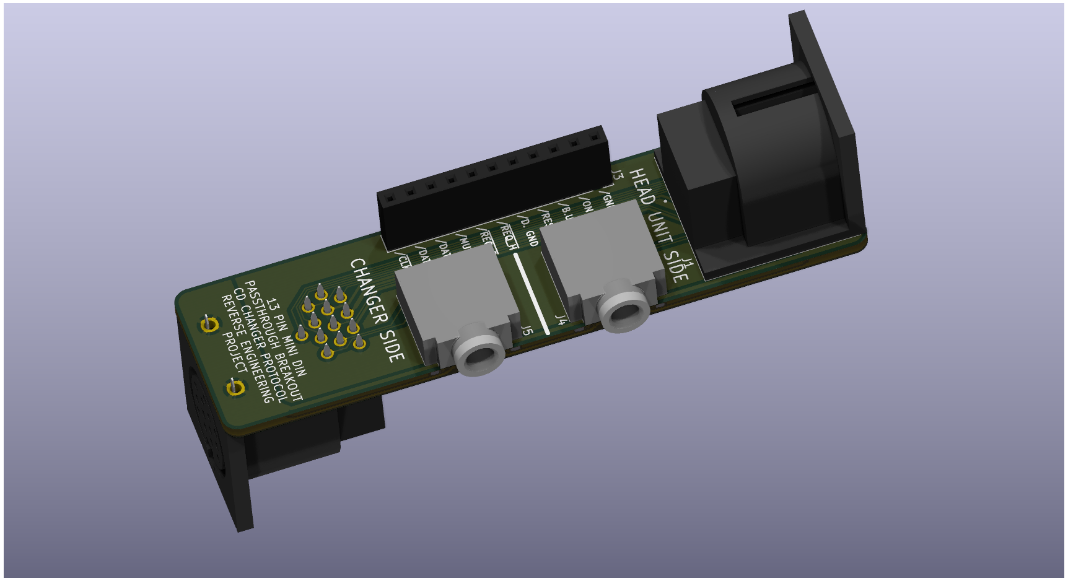
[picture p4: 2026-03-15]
assets/changer cable breakout 01.png

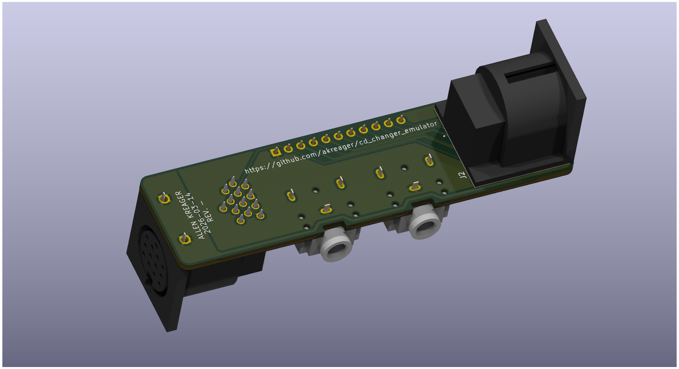
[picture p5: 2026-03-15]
assets/changer cable breakout 02.png

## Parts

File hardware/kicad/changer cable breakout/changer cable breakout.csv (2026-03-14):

Reference | Qty | Value | DNP | Exclude from BOM | Exclude from Board | Footprint | Datasheet
J1,J2 | 2 | SDD-130J |  |  |  | Library:CUI_SDD-130J | https://www.sameskydevices.com/product/resource/sds-j.pdf
J3 | 1 | Test Points |  |  |  | Library:PinSocket_1x11_P2.54mm_Vertical | ~
J4,J5 | 2 | AudioJack3 |  |  |  | Library:Jack_3.5mm_CUI_SJ1-3523N_Horizontal | ~

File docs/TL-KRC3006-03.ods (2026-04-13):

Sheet: Equipment Register
TL-KRC3006-03
Project: | Kenwood CD Changer Protocol Emulator (Open Source)
Date:
Tester:
Equipment / Component | Ref ID | Description / Model | Serial Number | Cal Due Date | Notes
Kenwood KRC-3006 | DUT | Head unit
Bench Power Supply | PWR-01 | 12 V / 2 A regulated
Staged Power Adapter | PWR-02 | Custom 2-stage ignition sim.
USB Logic Analyzer | LA-01 | SparkFun TOL-18627 or equiv.
Digital Multimeter | DMM-01
ATtiny1616 Breakout | MCU-01 | Adafruit #5690
UPDI Friend | PRG-01 | USB serial UPDI programmer
Raspberry Pi | SBC-01
PCM5102A DAC Module | MOD-01 | GY-PCM5102A
Level Shifter | MOD-04 | BSS138 module (breadboard)
Pass-Through Board | MOD-03 | DN-KRC3006-04 custom PCB
PulseView (sigrok) | SW-01 | Logic analyzer software
Arduino IDE + megaTinyCore | SW-02 | Firmware development
13-Pin DIN Cable | CBL-01 | Kenwood changer cable
3.5 mm Audio Cable | CBL-02 | Male-to-male

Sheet: Phase 1 — Handshake
TL-KRC3006-03
Project: | Kenwood CD Changer Protocol Emulator (Open Source)
Date:
Tester:
Level Shifter Verification
Check | Expected | Measured | P/F | Date | Tester |  | Notes
LV Rail | 3.3 V ±0.1 V
HV Rail | 5.0 V ±0.2 V
5 V Source |  |  |  |  |  |  | Record source used
Handshake Attempts
Attempt # | FW Version | HU Display | P/F | Response Time | Failure Mode | Date | Notes
Timing Comparison: ATtiny vs C717
Parameter | C717 Value | ATtiny Value | Within Spec? | Date |  |  | Notes
REQH→REQC delay
REQC assert duration
Response byte count
CLK edge alignment
Total frame time
Capture File Log
File Name | Date/Time | Duration | FW Version | Result |  |  | Notes
Phase 1 Overall Result:

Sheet: Phase 2 — Commands
TL-KRC3006-03
Project: | Kenwood CD Changer Protocol Emulator (Open Source)
Date:
Tester:
Status Response Verification
Check | Expected | Observed | P/F | Date | FW Ver | Notes
Disc/track display | Disc 1, Track 1
Transport controls enabled | Play/next/prev active
Time counter | Incrementing
Transport Command Testing
Command | Capture # | Cmd Hex Match? | Response Correct? | Display Update? | P/F | Notes
Play
Stop / Pause
Next Track
Previous Track
Fast Forward (hold)
Fast Reverse (hold)
Disc Up
Disc Down
Disc Select 1
Disc Select 2
Disc Select 3
Disc Select 4
Disc Select 5
Disc Select 6
Repeat Toggle
Shuffle Toggle
Automatic Sequence Testing
Scenario | Expected | Observed | P/F | Date |  | Notes
End of disc | Next disc or auto-advance
Disc change timeout | Resume within timeout
Malformed response | Retry/reset behavior
MUTE Line Verification
Action | MUTE Assert? | Duration (ms) | P/F | Date |  | Notes
Disc change | LOW before transition
MUTE release | HIGH after new track
30-Minute Stability Test
Start Time | End Time | Duration | Disconnects | Display Errors | Missed Polls | Notes
Phase 2 Overall Result:

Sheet: Phase 3 — Integration
TL-KRC3006-03
Project: | Kenwood CD Changer Protocol Emulator (Open Source)
Date:
Tester:
DAC Audio Chain Verification
Check | Expected | Result | P/F | Date | Notes
aplay -l shows DAC | Listed as sound device
Standalone audio test | Clean output, no hiss/hum
Ground config | Per Phase 1 continuity result
Serial Bridge Verification
Test | Expected | Result | P/F | Date | Notes
Pi → ATtiny cmd | ATtiny updates bus response
ATtiny → Pi cmd | Pi starts/stops playback
STATE updates | ~1/sec during playback
Non-blocking check | SPI not delayed by UART
End-to-End Command Validation
Command | Audio Correct? | Display Correct? | P/F | Date | Notes
Play
Stop / Pause
Next Track
Previous Track
Disc Change
Repeat
Shuffle
Fast Forward
Fast Reverse
Boundary Condition Testing
Scenario | Expected | Observed | P/F | Date | Notes
Last track of disc | Advance/stop/repeat
Track 1, prev | Wrap/stay/restart
Empty disc folder | Report “no disc”
Short tracks (<5 s) | No protocol issues
Long tracks (>10 min) | Time display correct
Audio Quality Assessment
Check | Result | Severity | P/F | Date | Notes
60/120 Hz hum |  |  |  |  | Ground loop indicator
Hiss (noise floor)
Clicks/pops/dropout |  |  |  |  | I2S or buffer issue
Output level |  |  |  |  | Adjust via ALSA mixer
Phase 3 Overall Result:

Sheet: Phase 4 — Soak Test
TL-KRC3006-03
Project: | Kenwood CD Changer Protocol Emulator (Open Source)
Date:
Tester:
2-Hour Sustained Playback Test
Parameter | Value |  |  |  |  | Notes
Start time
End time
Total duration |  |  |  |  |  | Min 2 hours
Total tracks played
Protocol disconnects |  |  |  |  |  | Target: 0
Audio dropouts |  |  |  |  |  | Target: 0
Display freezes |  |  |  |  |  | Target: 0
Serial bridge stalls |  |  |  |  |  | Target: 0
Power Cycle Recovery (5 attempts + rapid)
Attempt # | Off Duration | Recovery Time (s) | HU Resumed? | ATtiny Init? | Pi Rebooted? | Notes
1 | 5 sec
2 | 5 sec
3 | 5 sec
4 | 5 sec
5 | 5 sec
Rapid | 1 sec
Reset Line (CH-RST) Characterization
Parameter | Measured |  |  |  |  | Notes
Reset pulse present?
Pulse polarity |  |  |  |  |  | Active LOW or HIGH
Pulse width
Power-on → first reset
Reset → first poll
MUTE Line Disc Change Verification
Parameter | Expected | Measured | P/F |  |  | Notes
MUTE asserts before transition | LOW before audio change
MUTE releases after new track | HIGH after playback starts
Mute duration | 200–500 ms
Audio silent during mute | No audio output
Source Switching Behavior
Test | Expected | Observed | P/F |  |  | Notes
Switch away from CD-CH | CH-CON changes, polling stops
ATtiny enters idle | Detects source change
Switch back to CD-CH | Resume without reinit
HU power off (button) | Pin 3 stays 12 V
ATtiny detects no polling | Enters idle/sleep
Phase 4 Overall Result:

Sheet: Incidents
TL-KRC3006-03
Project: | Kenwood CD Changer Protocol Emulator (Open Source)
Date:
Tester:
Inc # | Severity | Phase/Step | Expected | Observed | Date | Root Cause | Resolution
Severity Legend:
Critical | Head unit damaged, smoke, or safety concern. STOP all testing.
Major | Protocol communication fails entirely; cannot proceed.
Minor | Specific command fails but overall protocol works. Can proceed.
Observation | Behavior differs from docs but does not affect functionality.
Inc # | Severity | Phase/Step | Expected | Observed | Date | Root Cause | Resolution

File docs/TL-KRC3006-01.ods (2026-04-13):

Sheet: Equipment Register
TL-KRC3006-01 Rev B
Project: | Kenwood CD Changer Protocol Emulator (Open Source)
Date:
Tester:
Equipment / Component | Ref ID | Description / Model | Serial Number | Cal Due Date | Notes
Kenwood KRC-3006 | KEN-01 | Head unit (DUT)
Kenwood KDC-C717 | KEN-02 | CD changer
Bench Power Supply | PWR-01
Staged Power Adapter | PWR-02 | Custom 2-stage ignition sim.
KRC-3006 DC Cord | PWR-03 | Power/speaker harness
USB Logic Analyzer | LA-01 | SparkFun TOL-18627 or equiv.
Digital Multimeter | DMM-01
13-Pin DIN Cable | CBL-01 | Kenwood changer cable
13-Pin Breakout Board | MOD-02 | Prototyping board
Pass-Through Board | MOD-03 | DN-KRC3006-04 custom PCB
PulseView (sigrok) | SW-01 | Logic analyzer software

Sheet: Phase 1 — Static Verification
TL-KRC3006-01 Rev B
Project: | Kenwood CD Changer Protocol Emulator (Open Source)
Date:
Tester:
Initial Power-Up
Step | Action | Expected | Result | P/F | Date | Tester | Notes
1 | PSU on, constant power on | PSU stable at 12.0 V
2 | Ignition power on | Head unit powers on
3 | Idle current draw | 0.5–1.5 A
4 | Select CD-CH source | Error/search display
13-Pin DIN Voltage Measurements
Pin | Signal | Function | Dir | Expected V | Measured V | P/F | Notes
1 | CH-REQH | Request (H→C) | Out | Logic HIGH idle
2 | GND | Digital Ground | — | 0 V (ref)
3 | +12V | Power Supply | Out | 11.5–12.5 V
4 | CH-CON | Changer Connect | Out | Toggle w/ source
5 | CH-MUTE | Mute Request | In | Logic HIGH idle
6 | AGND | Audio Ground | — | 0 V / isolated
7 | CH-RST | Reset | Out | Logic HIGH idle
8 | R-CH | Right Audio | In | 0 V (no source)
9 | CH-REQC | Request (C→H) | In | Logic HIGH idle
10 | CH-DATAC | Data (C→H) | In | Logic LOW idle
11 | CH-DATAH | Data (H→C) | Out | Logic LOW idle
12 | L-CH | Left Audio | In | 0 V (no source)
13 | CLK | Clock | Out | Toggling / 0 V
Ground Continuity
Test | Expected | Result | P/F | Date | Tester | Notes
Pin 2 ↔ Pin 6 | Continuity or isolated
Phase 1 Overall Result:

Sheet: Phase 2A — Idle Capture
TL-KRC3006-01 Rev B
Project: | Kenwood CD Changer Protocol Emulator (Open Source)
Date:
Tester:
Clock and Timing Measurements
Capture # | Clock Freq (kHz) | Polling Interval | CLK Behavior | REQH Behavior | P/F | Notes
Idle Message Decoding
Capture # | Total Bits | Decoded Hex (H→C) | Header Bytes | Command Byte | Data Bytes | Notes / Comparison to Mictronics
Capture File Log
File Name | Date/Time | Duration (s) | Sample Rate | Description | P/F | Notes
Phase 2A Overall Result:

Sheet: Phase 2B — Changer Capture
TL-KRC3006-01 Rev B
Project: | Kenwood CD Changer Protocol Emulator (Open Source)
Date:
Tester:
Setup Verification
Check | Expected | Observed | P/F | Date | Tester | Notes
Breakout board inline | Connected
Magazine loaded | Disc in slot 1
No shorts to GND/PWR | All clear
Initialization Sequence
Capture # | Hex (H→C) | Hex (C→H) | Handshake Detail | CH-CON State | CH-MUTE State | Notes
Steady-State Status Messages
Capture # | Hex (H→C) | Hex (C→H) | Disc # | Track # | State | Notes
Capture File Log
File Name | Date/Time | Duration (s) | Sample Rate | Description | P/F | Notes
Phase 2B Overall Result:

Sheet: Phase 3 — Command Map
TL-KRC3006-01 Rev B
Project: | Kenwood CD Changer Protocol Emulator (Open Source)
Date:
Tester:
Command Mapping
Button / Action | Capture # | Cmd Hex (H→C) | Response Hex (C→H) | State Change | Matches Mictronics? | Notes
Play
Pause
Next Track
Previous Track
Fast Forward (hold)
Fast Reverse (hold)
Disc Up
Disc Down
Disc Select 1
Disc Select 2
Disc Select 3
Disc Select 4
Disc Select 5
Disc Select 6
Repeat Toggle
Random/Shuffle Toggle
Next Track (last track)
Prev Track (track 1)
Disc Up (last disc)
Disc Select (empty slot)
Capture File Log
File Name | Date/Time | Duration (s) | Sample Rate | Description | P/F | Notes
Phase 3 Overall Result:

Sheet: Incidents
TL-KRC3006-01 Rev B
Project: | Kenwood CD Changer Protocol Emulator (Open Source)
Date:
Tester:
Inc # | Severity | Phase/Step | Expected | Observed | Date | Root Cause | Resolution
Severity Legend:
Critical | Head unit damaged, smoke, or safety concern. STOP all testing.
Major | Protocol communication fails entirely; cannot proceed.
Minor | Specific command fails but overall protocol works. Can proceed.
Observation | Behavior differs from docs but does not affect functionality.
Inc # | Severity | Phase/Step | Expected | Observed | Date | Root Cause | Resolution

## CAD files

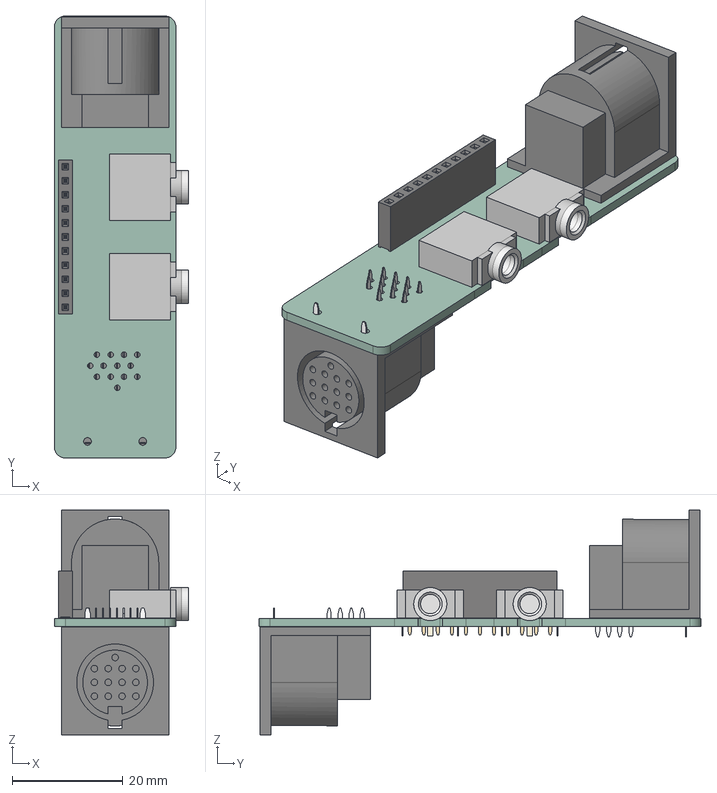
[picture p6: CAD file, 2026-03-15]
hardware/kicad/changer cable breakout/changer cable breakout.step
24.3 x 80.0 x 40.7 mm
Jack_3.5mm_CUI_SJ1-3523N_Horizontal x 2
SDD-130J x 2
PinSocket_1x11_P2.54mm_Vertical
changer cable breakout_PCB

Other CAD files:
hardware/kicad/changer cable breakout/changer cable breakout.3mf

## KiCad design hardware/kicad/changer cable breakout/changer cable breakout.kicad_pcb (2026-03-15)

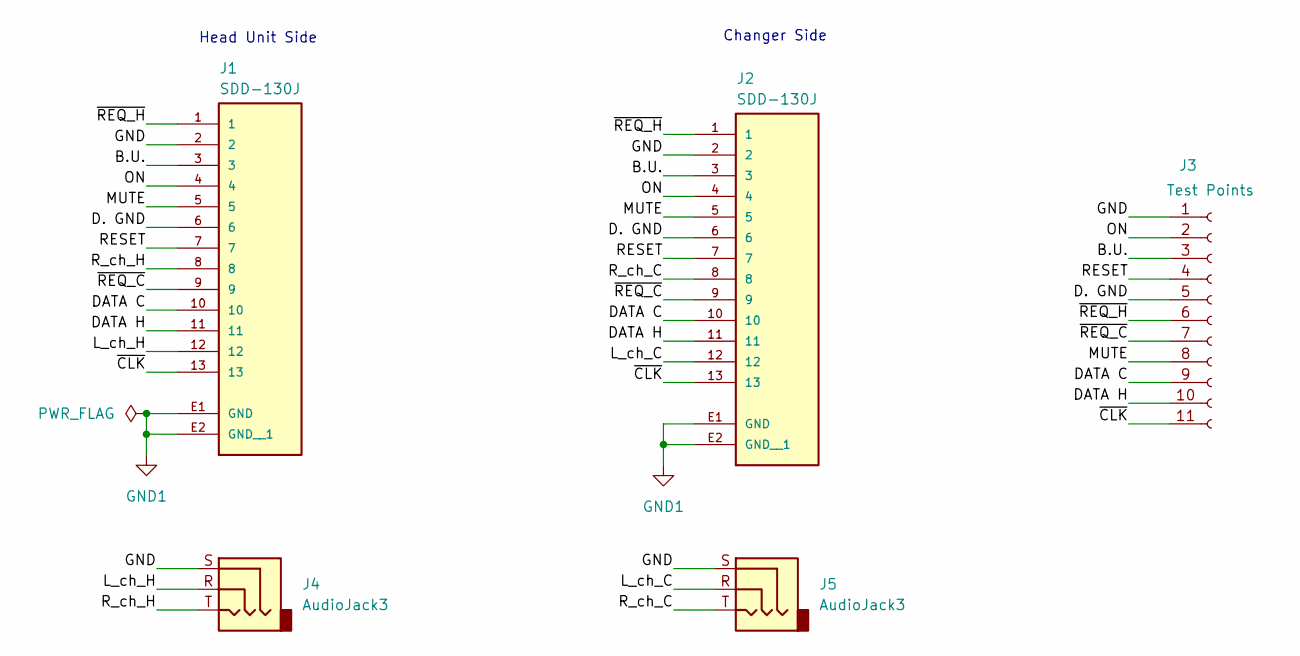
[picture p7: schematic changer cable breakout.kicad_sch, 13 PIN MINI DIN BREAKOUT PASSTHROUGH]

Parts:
J1, J2: SDD-130J; CUI_SDD-130J; PARTREV 1.06/02-13-2020
J3: Test Points; PinSocket_1x11_P2.54mm_Vertical
J4, J5: AudioJack3; Jack_3.5mm_CUI_SJ1-3523N_Horizontal

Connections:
/B.U.: J1.3, J2.3, J3.3
/D. GND: J1.6, J2.6, J3.5
/DATA C: J1.10, J2.10, J3.9
/DATA H: J1.11, J2.11, J3.10
/GND: J1.2, J2.2, J3.1, J4.S, J5.S
/L_ch_C: J2.12, J5.R
/L_ch_H: J1.12, J4.R
/MUTE: J1.5, J2.5, J3.8
/ON: J1.4, J2.4, J3.2
/RESET: J1.7, J2.7, J3.4
/R_ch_C: J2.8, J5.T
/R_ch_H: J1.8, J4.T
/~CLK: J1.13, J2.13, J3.11
/~REQ_C: J1.9, J2.9, J3.7
/~REQ_H: J1.1, J2.1, J3.6
GND1: J1.E1 (GND), J1.E2 (GND__1), J2.E1 (GND), J2.E2 (GND__1)

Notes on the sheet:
Head Unit Side
Changer Side

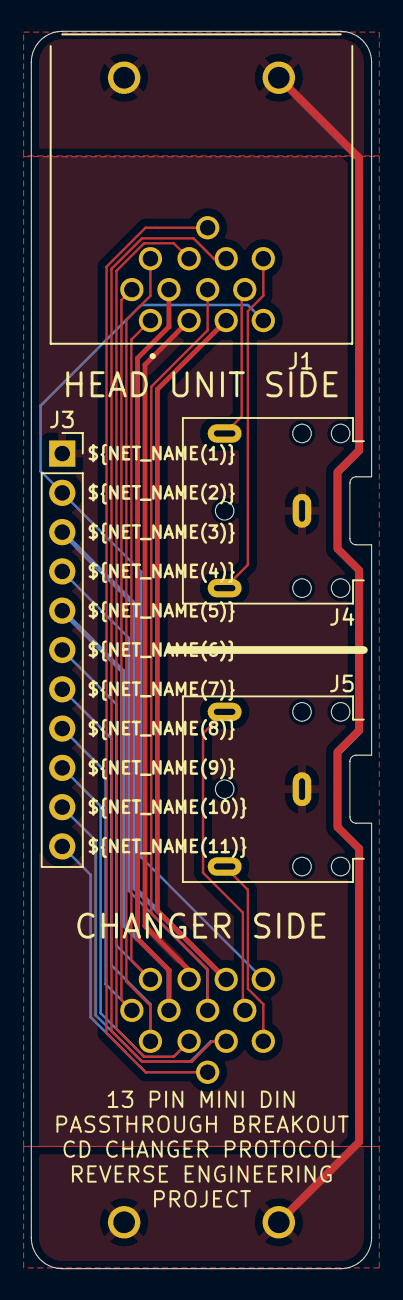
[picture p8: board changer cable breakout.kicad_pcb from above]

Board: 2 copper layers, 22.0 x 80.0 mm, 5 parts (1 on the bottom side), 16 nets.

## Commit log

2026-03-08 add reference docs
    Add service manuals for KRC-3006 and KDC-CX85. Add schematics for KRC-3006. Add KRC-3006 owners manual.
2026-03-08 Add documents
    [TL-KRC3006-001.ods]
2026-03-09 Start KiCAD project
    [emulator hat.kicad_pcb, emulator hat.kicad_sch]
2026-03-09 Update and rename SA-KRC3006-001-Schematic-Analysis.md to DN-KRC3006-02.md
2026-03-10 Add 13pin mini DIN connector datasheet
2026-03-10 rename and update test plan and test log docs.
    [TL-KRC3006-001.ods, TL-KRC3006-01.ods]
2026-03-10 start symbol and footprint library for project
2026-03-10 move emulator hat to subfolder
    [emulator hat.kicad_pcb, emulator hat.kicad_sch]
2026-03-10 start cable breakout design
    [changer cable breakout.kicad_pcb, changer cable breakout.kicad_sch]
2026-03-11 make schematic and start layout
    [changer cable breakout.kicad_pcb, changer cable breakout.kicad_sch]
2026-03-14 update footprints
2026-03-14 finish breakout design
    [changer cable breakout.csv, changer cable breakout.kicad_pcb, changer cable breakout.kicad_sch]
2026-03-15 Finalize breakout design
    [changer cable breakout.3mf, changer cable breakout.kicad_pcb, changer cable breakout.step]
2026-03-15 Update changer cable breakout.3mf
    [changer cable breakout.3mf]
2026-03-15 Add test plan and test log for breakout board
2026-03-21 Update .gitignore
    hide kicad 10 .history
2026-03-21 Update DN-KRC3006-01.md
    updated for decision to run attiny1616 at 3.3v and add level shifters for changer bus.
2026-03-21 Update DN-KRC3006-01.md
    update for decision to use separate uarts for communication and updi programming from pi to attiny.
2026-04-11 update board assembly test plan and test log
    rev b
2026-04-11 complete board serial number 1
2026-04-13 Update test plan 01
    Rev B
    [TL-KRC3006-01.ods]
2026-04-13 Create Test plan 3
    4 phases of protocol emulation creation
    [TL-KRC3006-03.ods]

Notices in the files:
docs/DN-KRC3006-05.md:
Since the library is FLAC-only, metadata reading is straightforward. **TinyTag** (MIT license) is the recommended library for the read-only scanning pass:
